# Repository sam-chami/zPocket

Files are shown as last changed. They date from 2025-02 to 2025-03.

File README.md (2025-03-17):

# zPocket
> WIP

certification-mark-ES000051-wide (https://certification.oshwa.org/es000051.html)

The zPocket is a modular, handheld portable Linux device with a square touchscreen as well as keyboard for input. The modularity allows you to use it as a Cyberdeck, Phone, or even satellite communicator.

## Significant features:
- Touchscreen 720x720 panel
- Blackberry Q10 Keyboard
- Raspberry Pi Compute Module 5
- Mini PCIe connector
- USB-C Dual-role Port and mini HDMI
- Magnetometer (Compass)
- Battery Charging and Gauge

## Assembly Render
Front                                                   |  Back
:------------------------------------------------------:|:--------------------------------------:
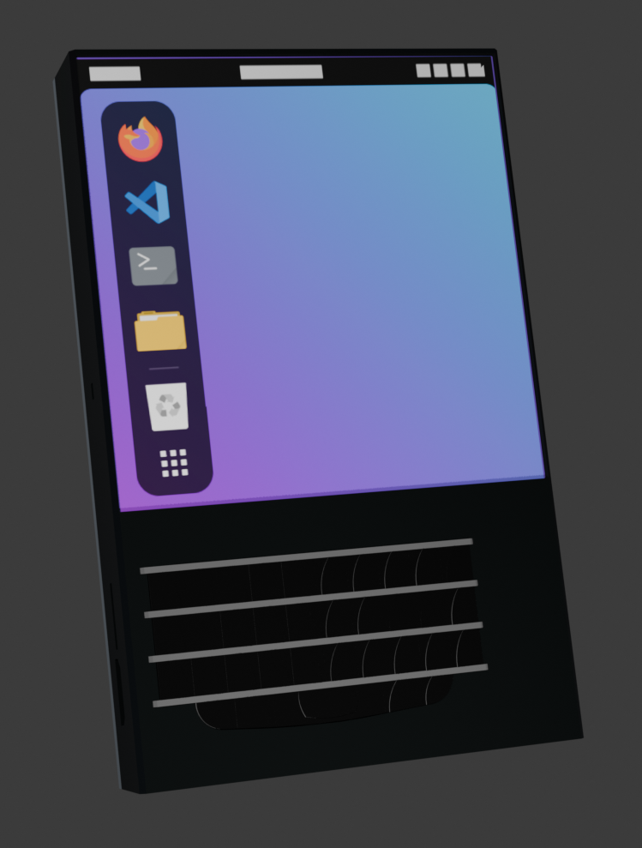
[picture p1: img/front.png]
Front of the zPocket inside the case
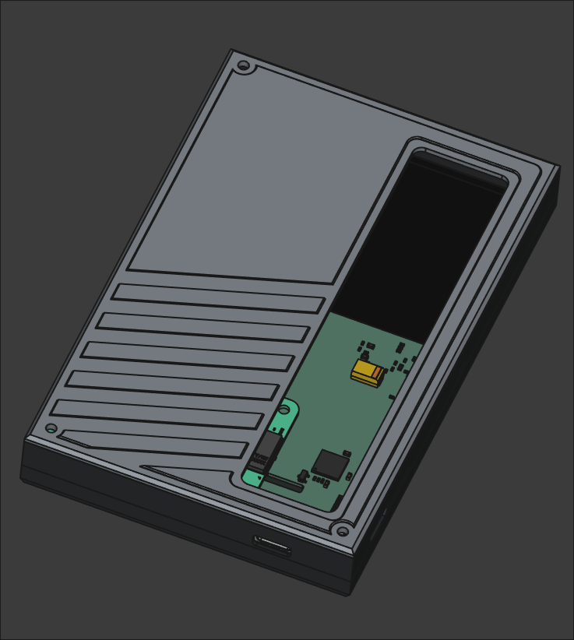
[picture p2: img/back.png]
Back of the zPocket.
  |  

## PCB
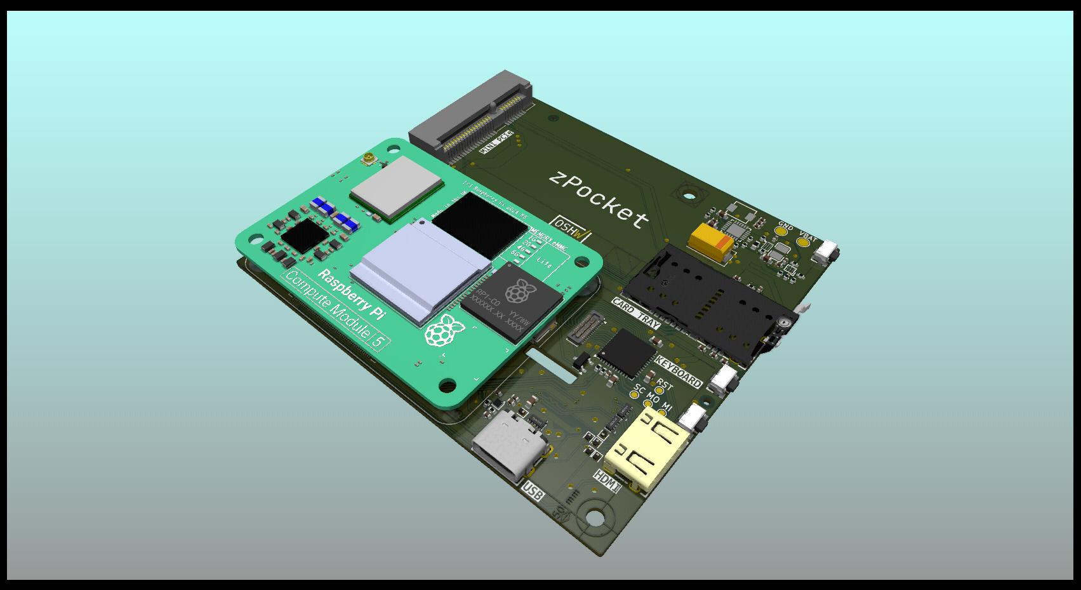
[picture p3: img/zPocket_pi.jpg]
Front of zPocket PCB


## Documentation
The documentation is available in [this repository's wiki page](https://github.com/sam-chami/zPocket/wiki)

## License
The zPocket hardware has a "CERN Open Hardware Licence Version 2 - Strongly Reciprocal".

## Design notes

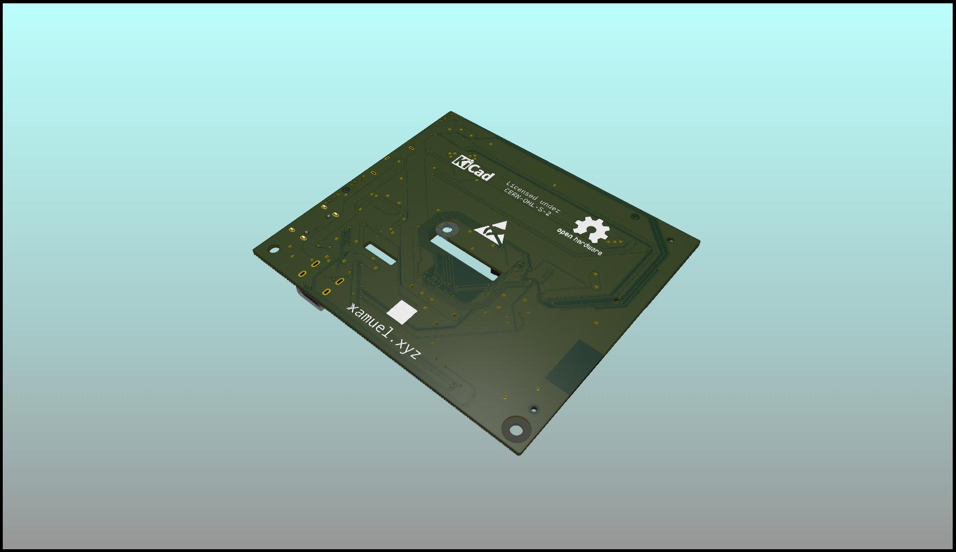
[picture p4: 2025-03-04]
img/zPocket_back.jpg

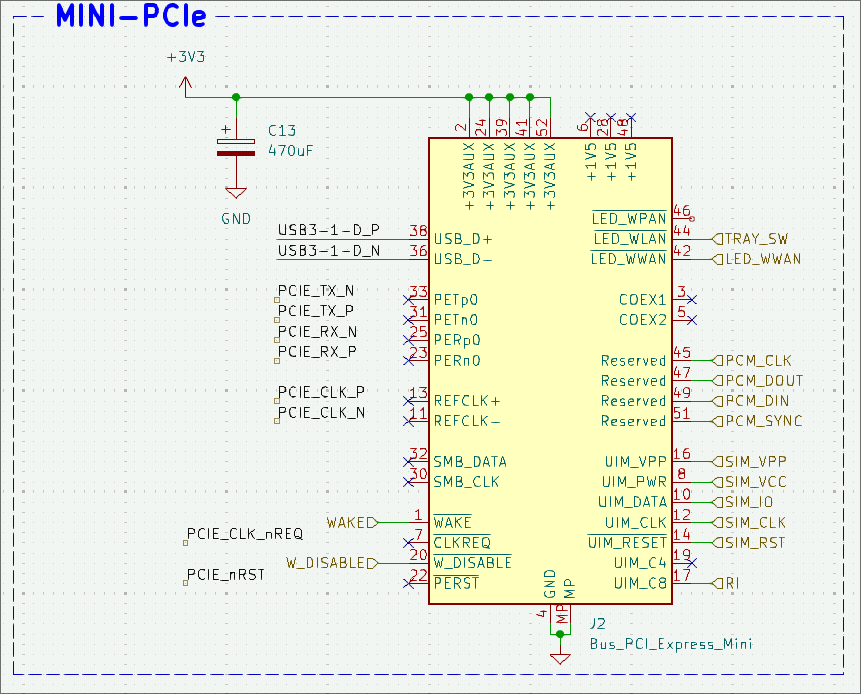
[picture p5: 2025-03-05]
img/mini_pcie.png

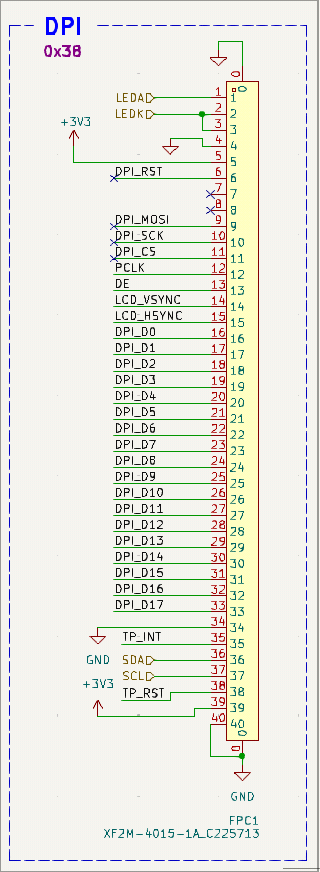
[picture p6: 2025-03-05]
img/DPI.png

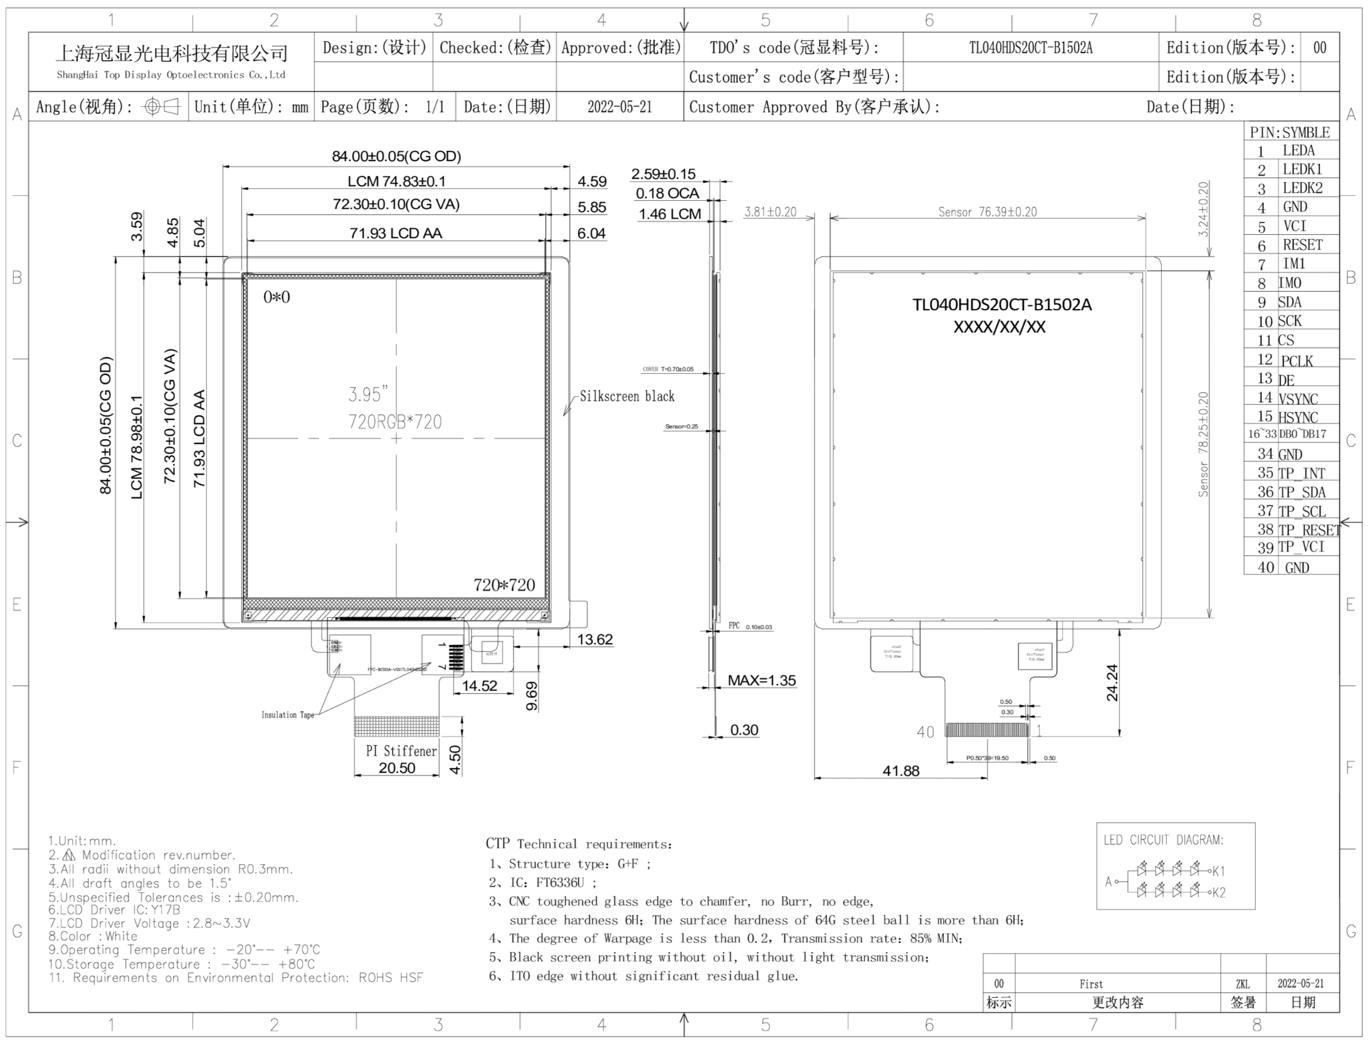
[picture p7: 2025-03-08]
img/display_draw.png

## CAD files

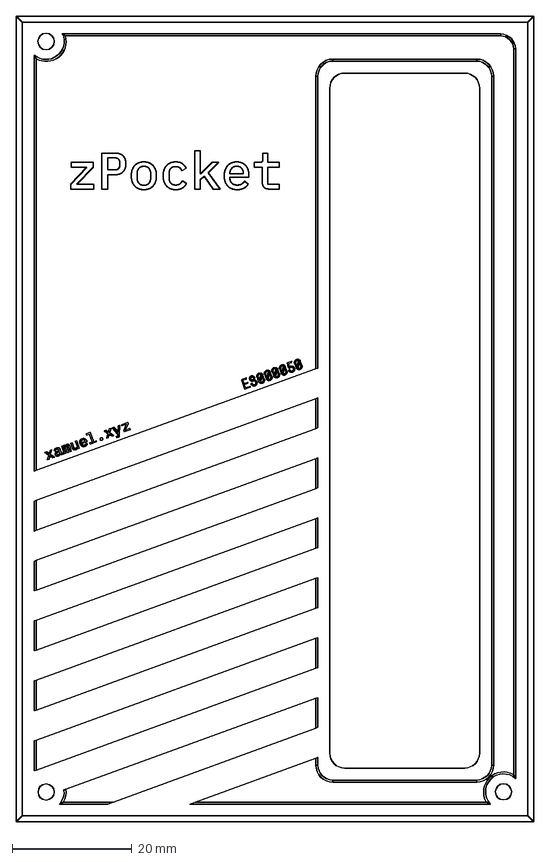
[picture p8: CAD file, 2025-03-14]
Case/drawing.dxf
86.3 x 134.5 mm

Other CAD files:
Case/zPocket-Back.step
Case/zPocket-Back.dfx.step
Case/pcb.step

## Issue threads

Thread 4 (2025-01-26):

Battery

sam-chami, 2025-01-26:
Everything is done, but in

### **THE CHARGER**

- TODO: Set resistor divider according to temp range.

### **THE GAUGE**

- TODO: Setup BIN pin according to removable or fixed battery.

### **BUCK BOOST**

- Set enable pin in order to turn it off with the CM4/5

sam-chami, 2025-03-04:
Finished, right now we're using a normal soldered battery, if possible we will use a removable one.

Closed 2025-03-04.

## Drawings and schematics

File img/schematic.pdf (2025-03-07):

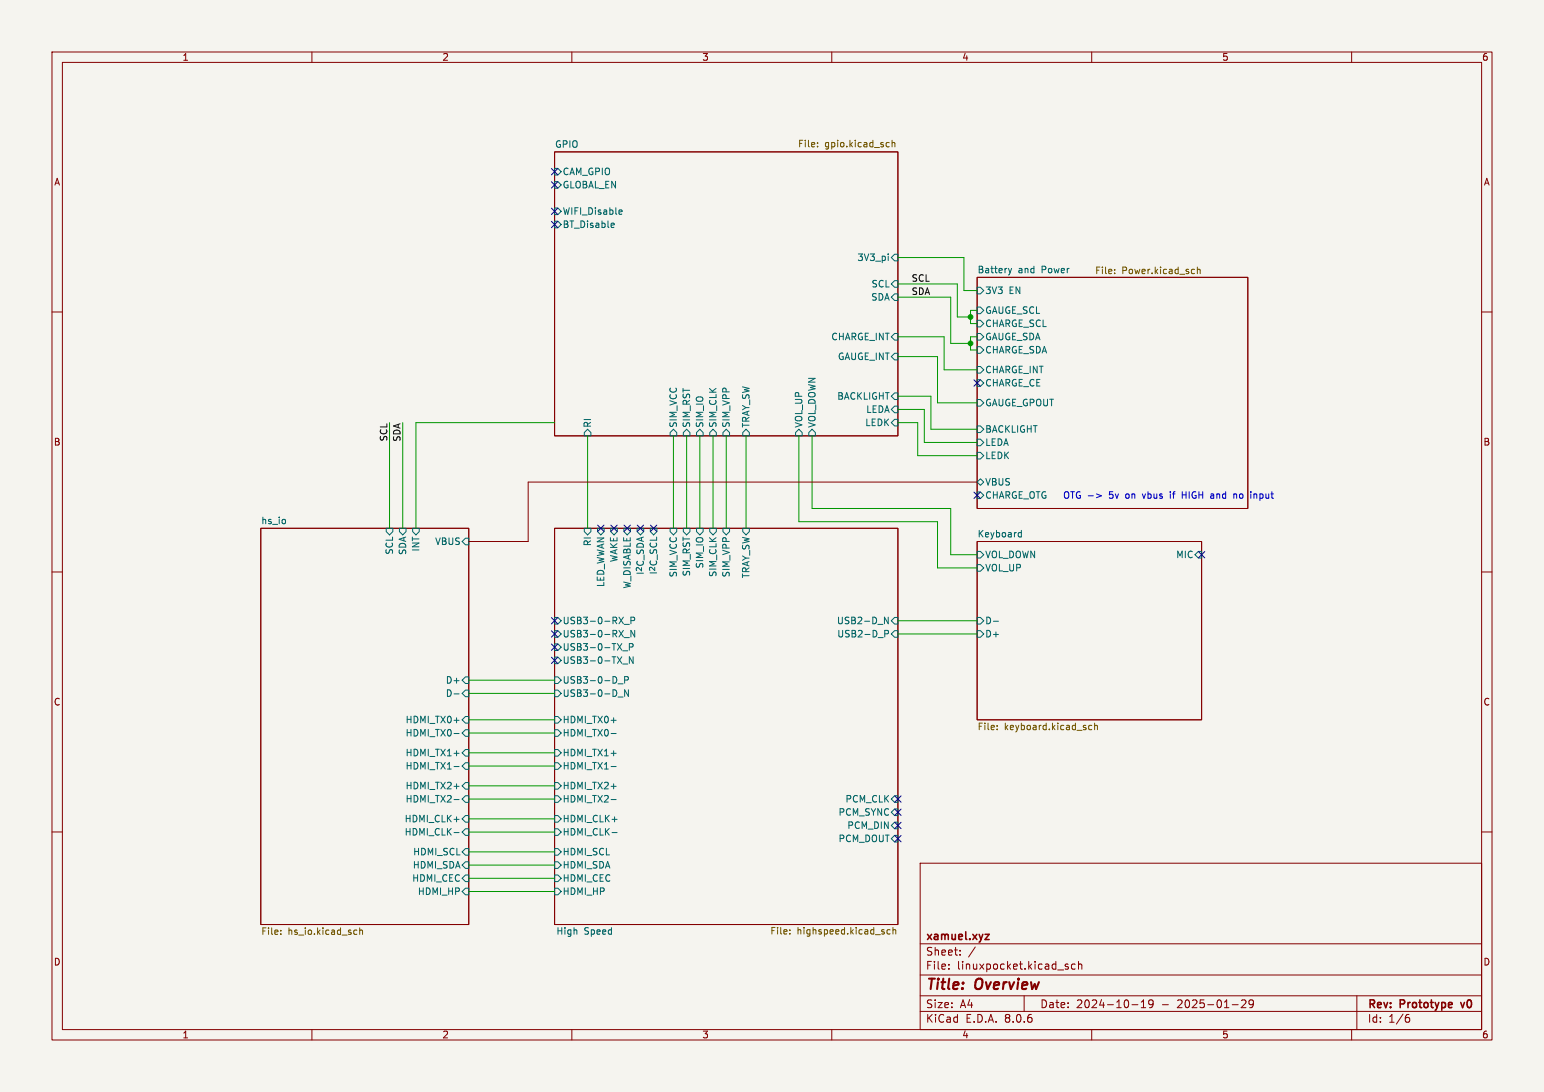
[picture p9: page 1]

Keyboard File: keyboard.kicad_sch SDA
hs_io File: hs_io.kicad_sch

File: linuxpocket.kicad_sch Sheet: / xamuel.xyz HDMI_TX1+ HDMI_TX1- HDMI_TX0+ HDMI_TX2+ HDMI_TX2- HDMI_TX0- HDMI_CLK- HDMI_CLK+ HDMI_SCL HDMI_SDA HDMI_CEC

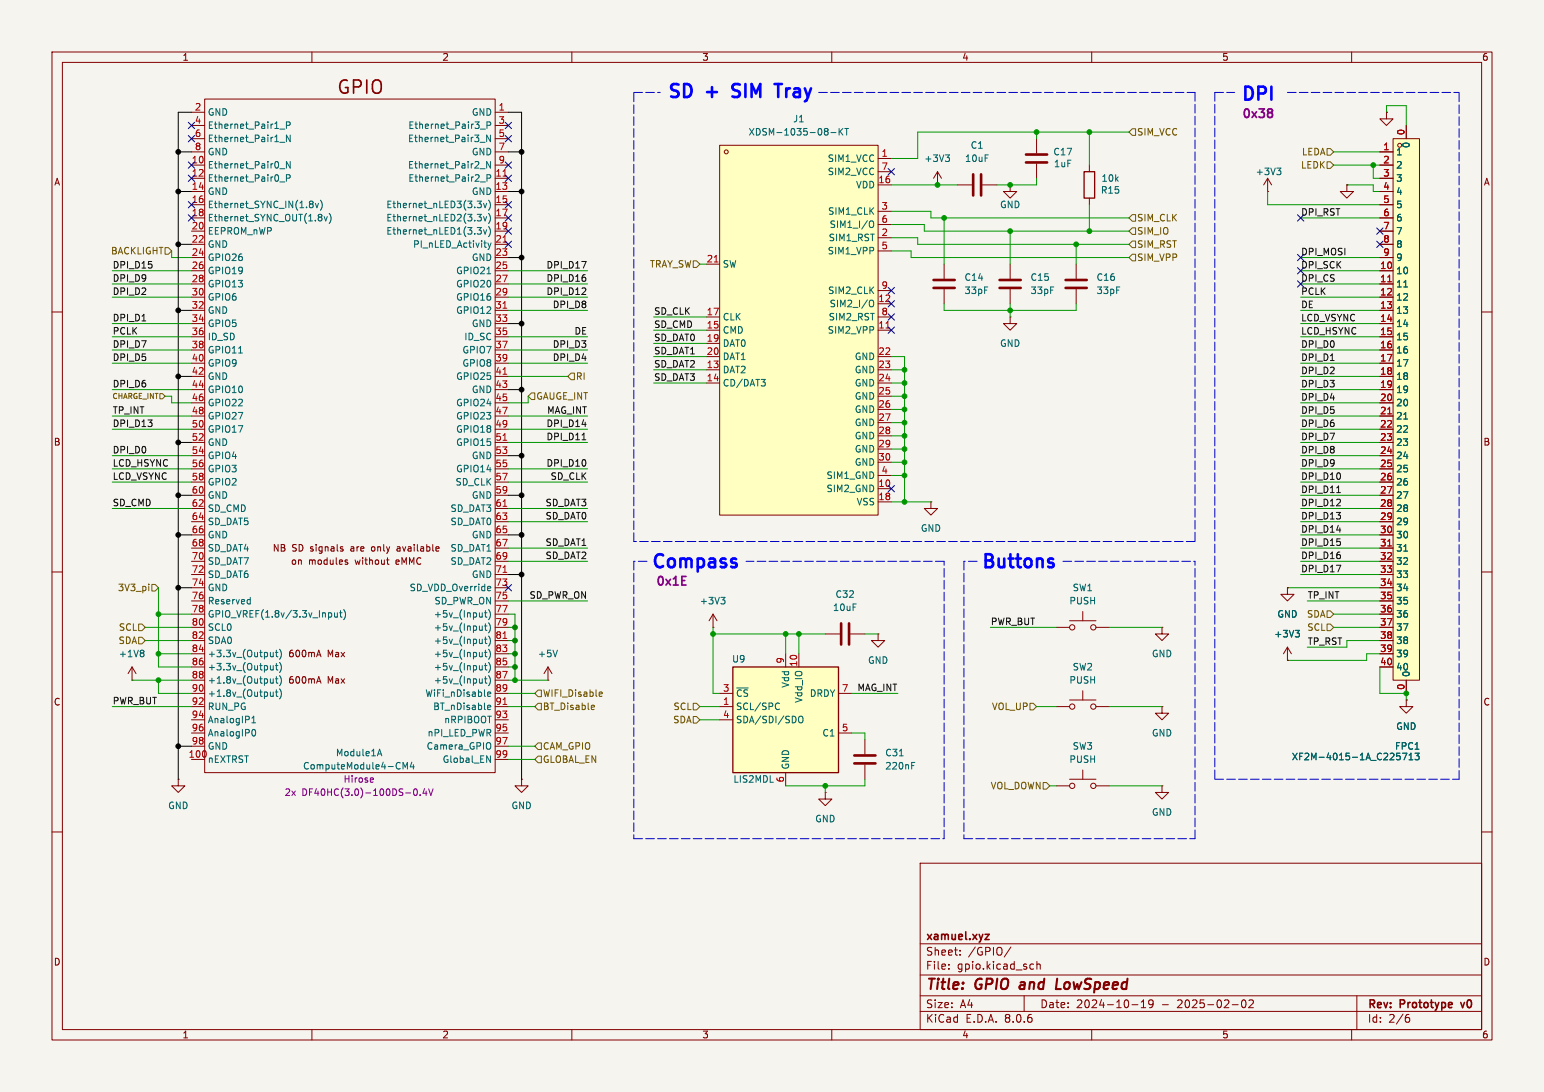
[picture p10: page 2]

600mA Max 600mA Max NB SD signals are only available

File: gpio.kicad_sch Sheet: /GPIO/ xamuel.xyz C32

Id: 2/6 Title: GPIO and LowSpeed

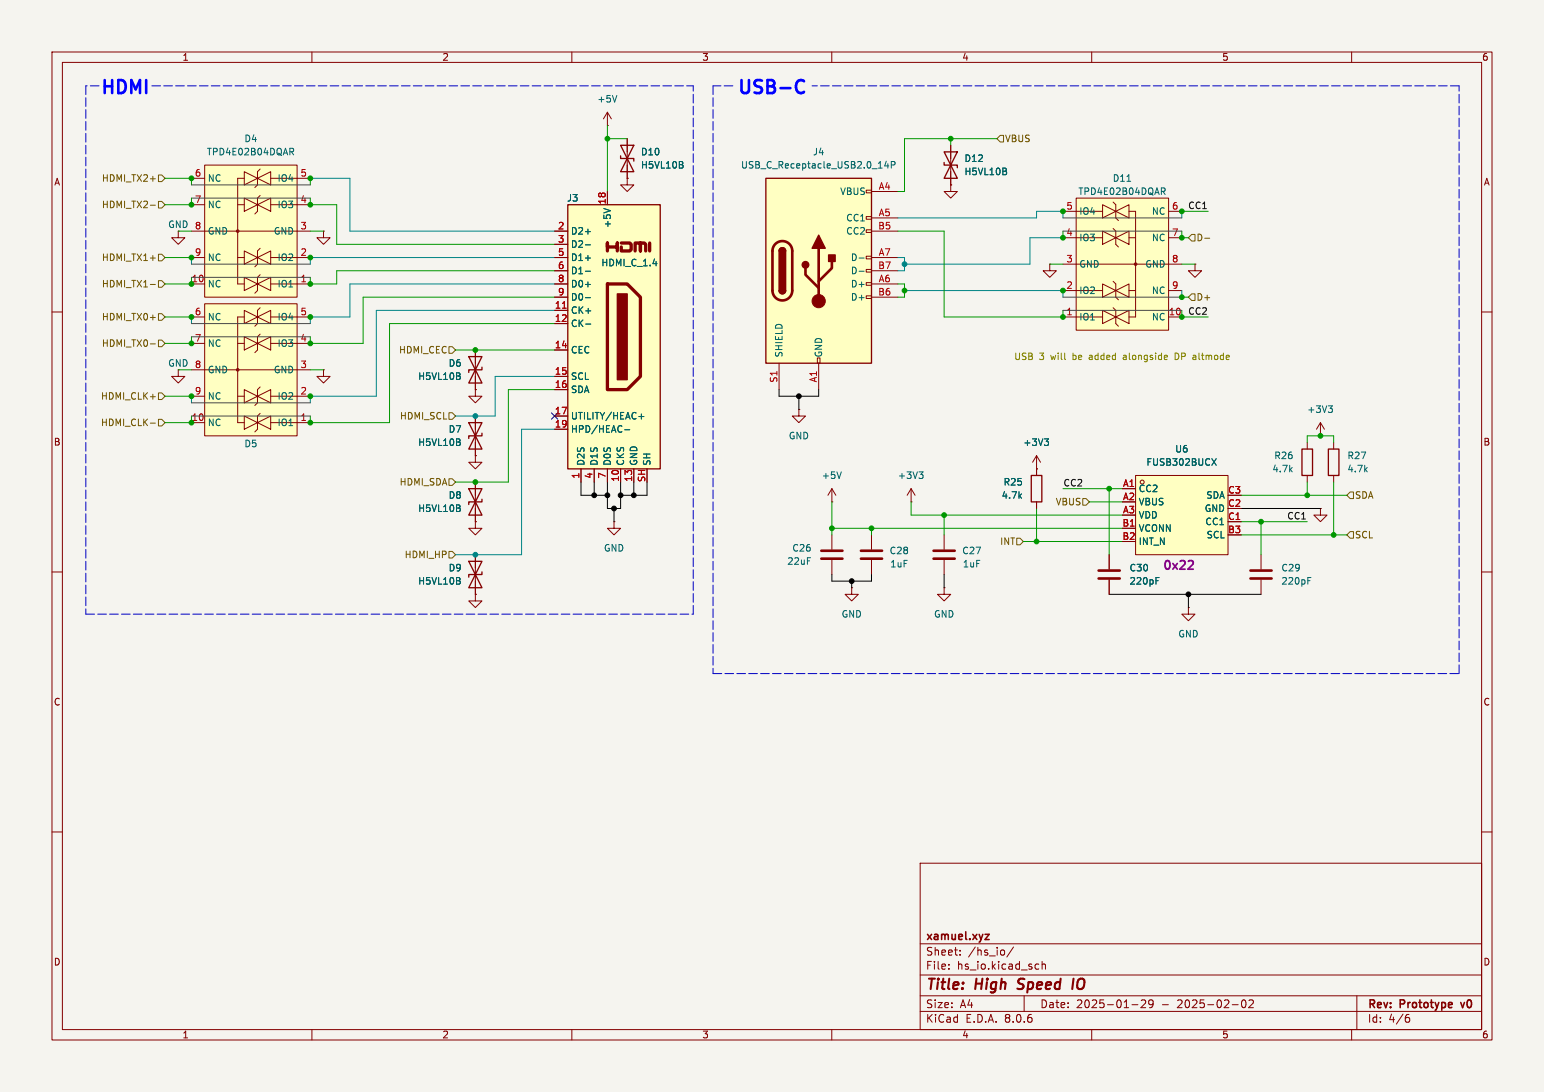
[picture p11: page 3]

1 CKS 10 CK+ 11 CK- 12 GND 13 CEC 14 SCL 15 SDA 16 UTILITY/HEAC+ 17 +5V 18 HPD/HEAC- 19 D2+ 2 D2- 3 D1S

xamuel.xyz
File: hs_io.kicad_sch Sheet: /hs_io/
Id: 4/6 Title: High Speed IO

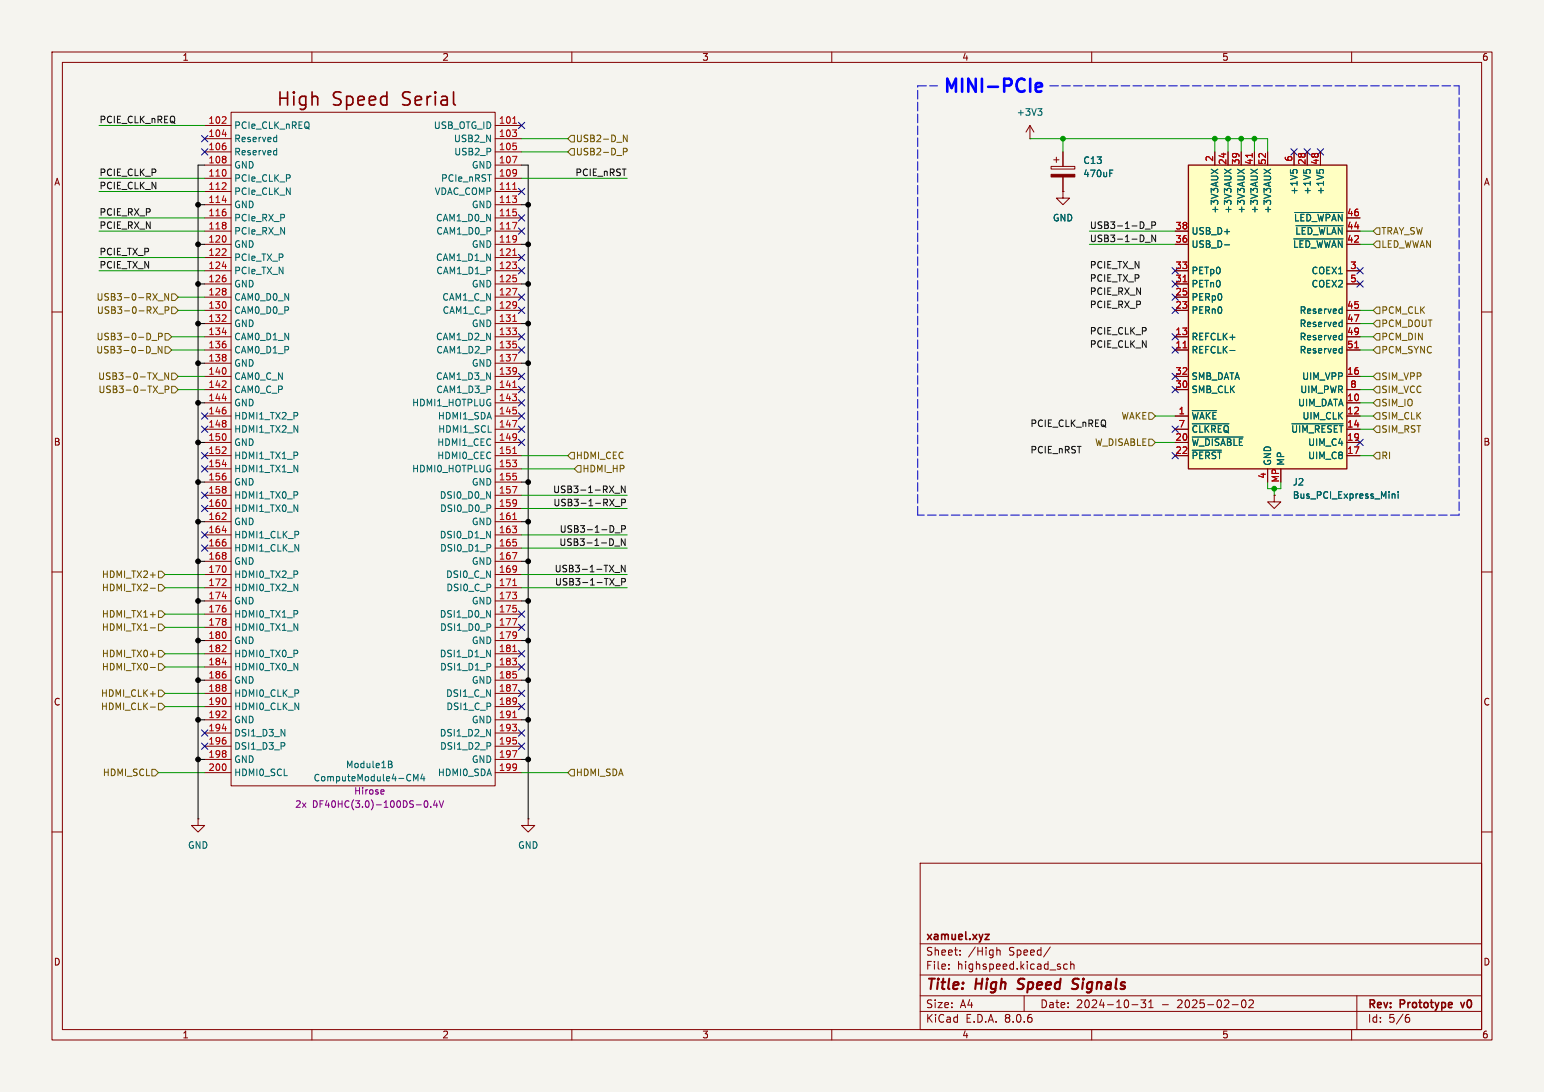
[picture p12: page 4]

xamuel.xyz
Id: 5/6 Title: High Speed Signals

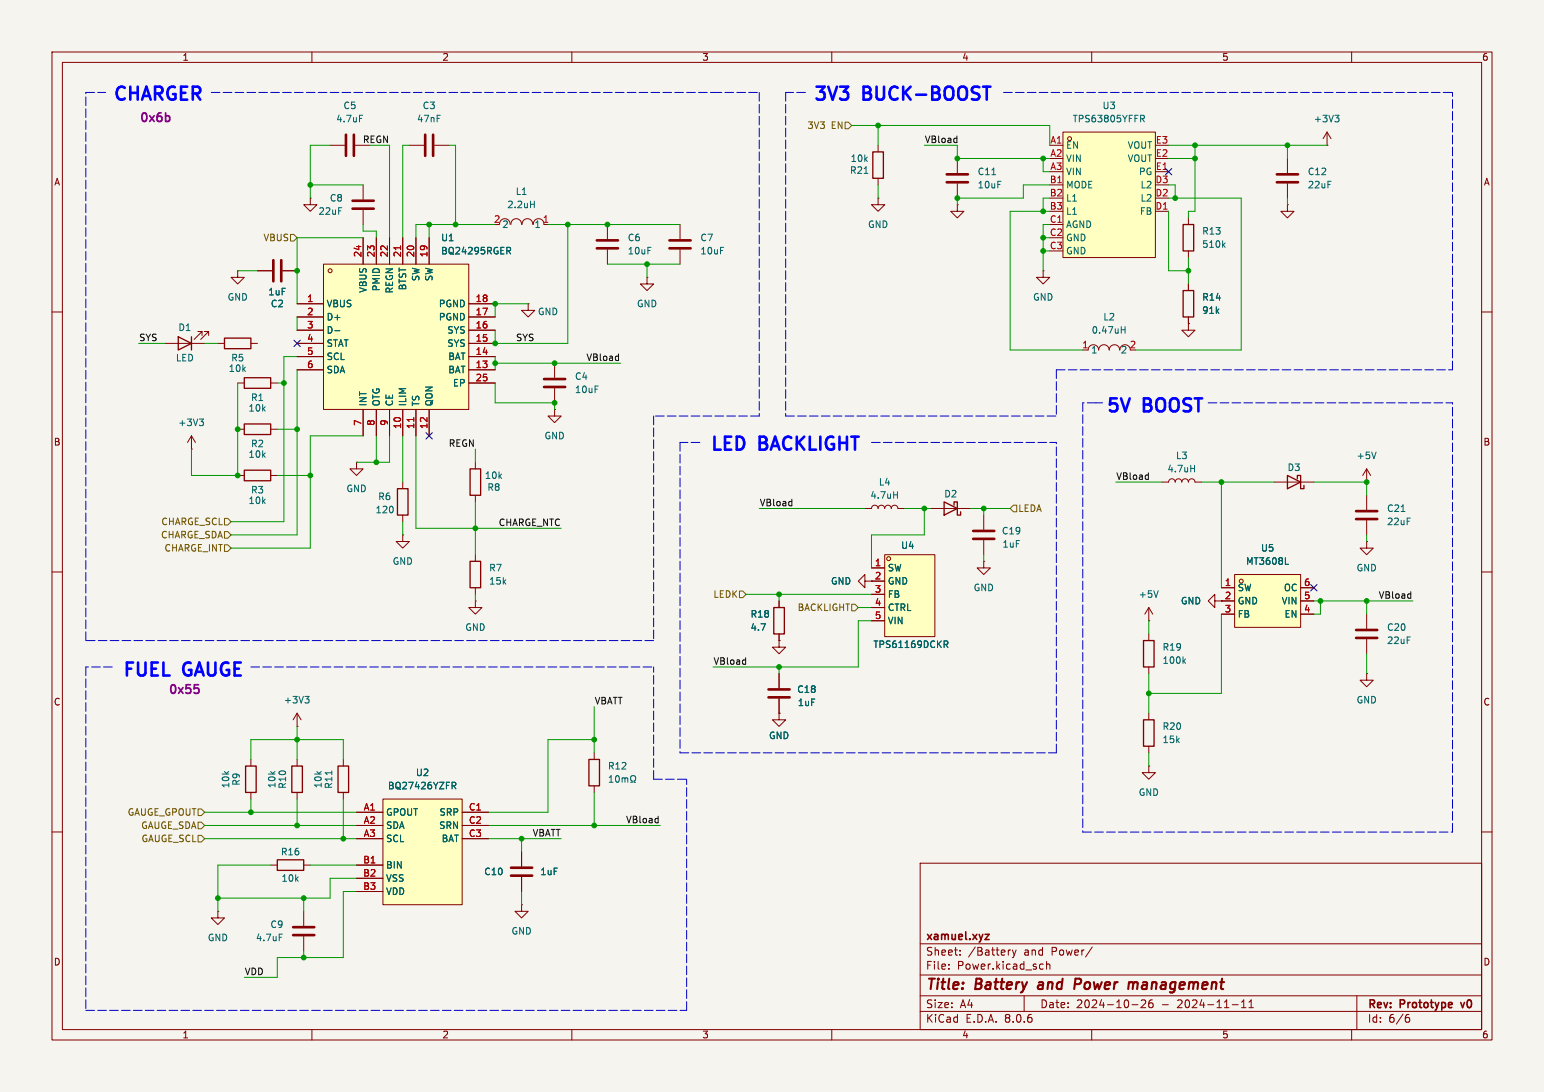
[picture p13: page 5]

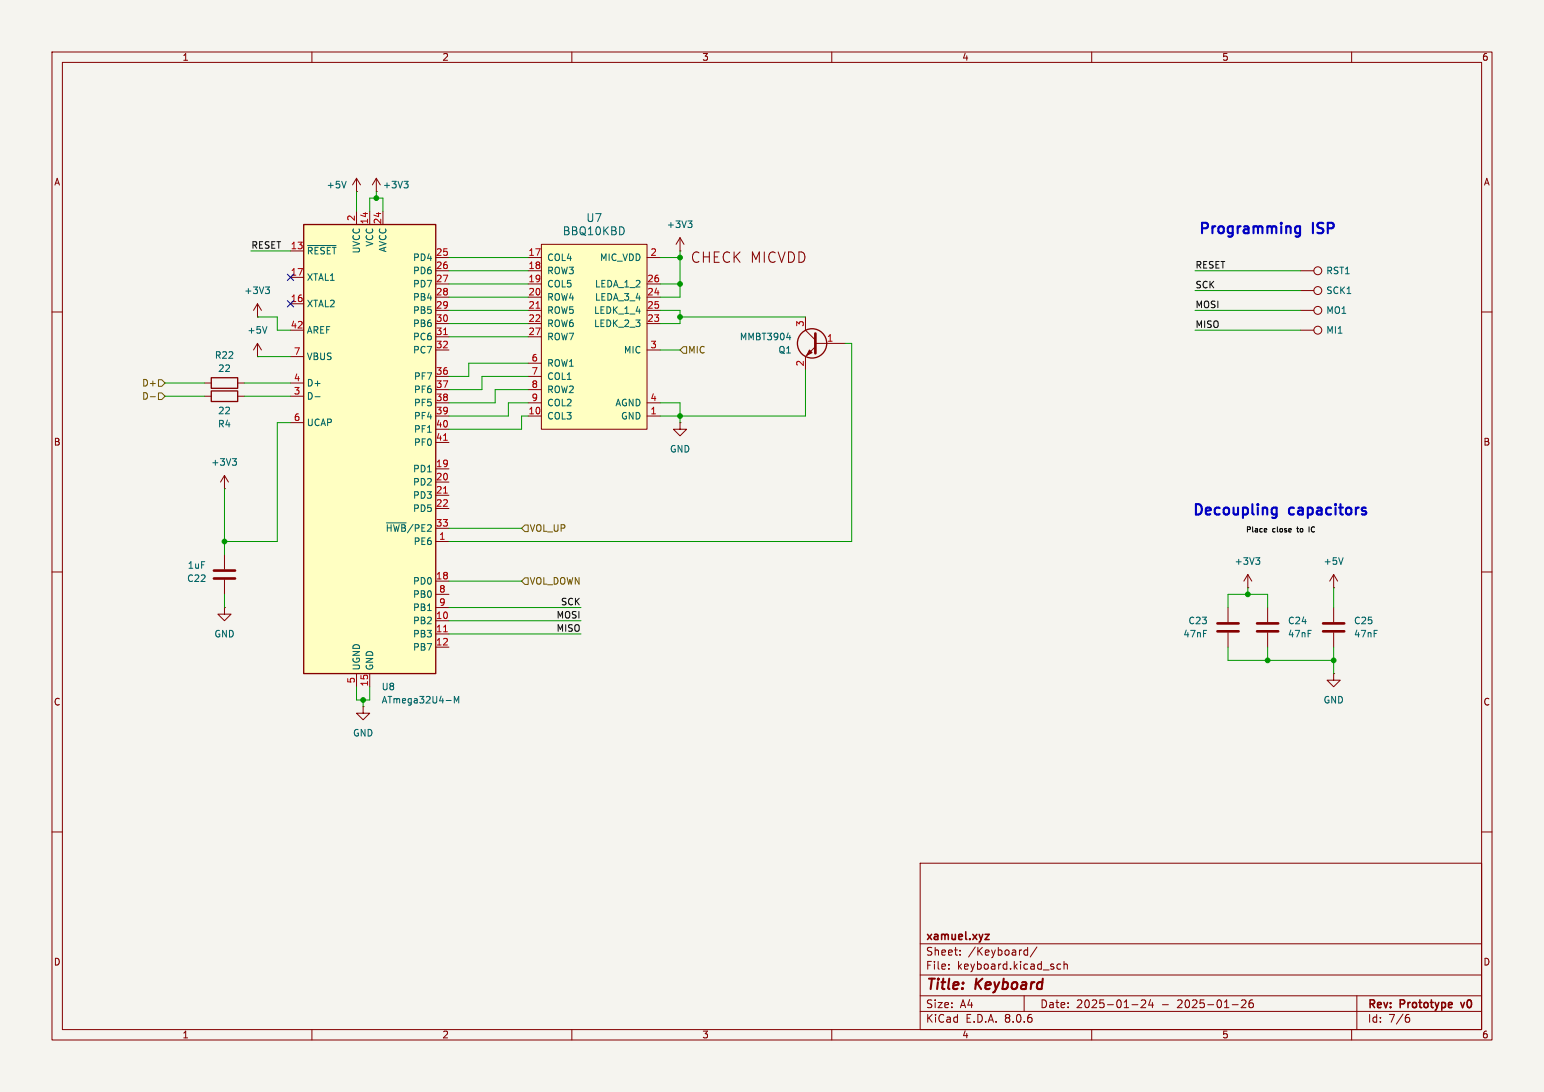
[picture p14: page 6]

2 PD2 20 PD3 21 PD5 22 AVCC 24 PD4 25 PD6 26 PD7 27 PB4 28 PB5 29 D- 3 PB6 30 PC6 31 PC7 32 ~{HWB}/PE233 PF7 36 PF6 37 PF5 38 PF4 39 D+ 4 PF1 40 PF0 41 AREF 42 UGND

Place close to IC Decoupling capacitors

xamuel.xyz
File: keyboard.kicad_sch Sheet: /Keyboard/
Id: 7/6 Title: Keyboard

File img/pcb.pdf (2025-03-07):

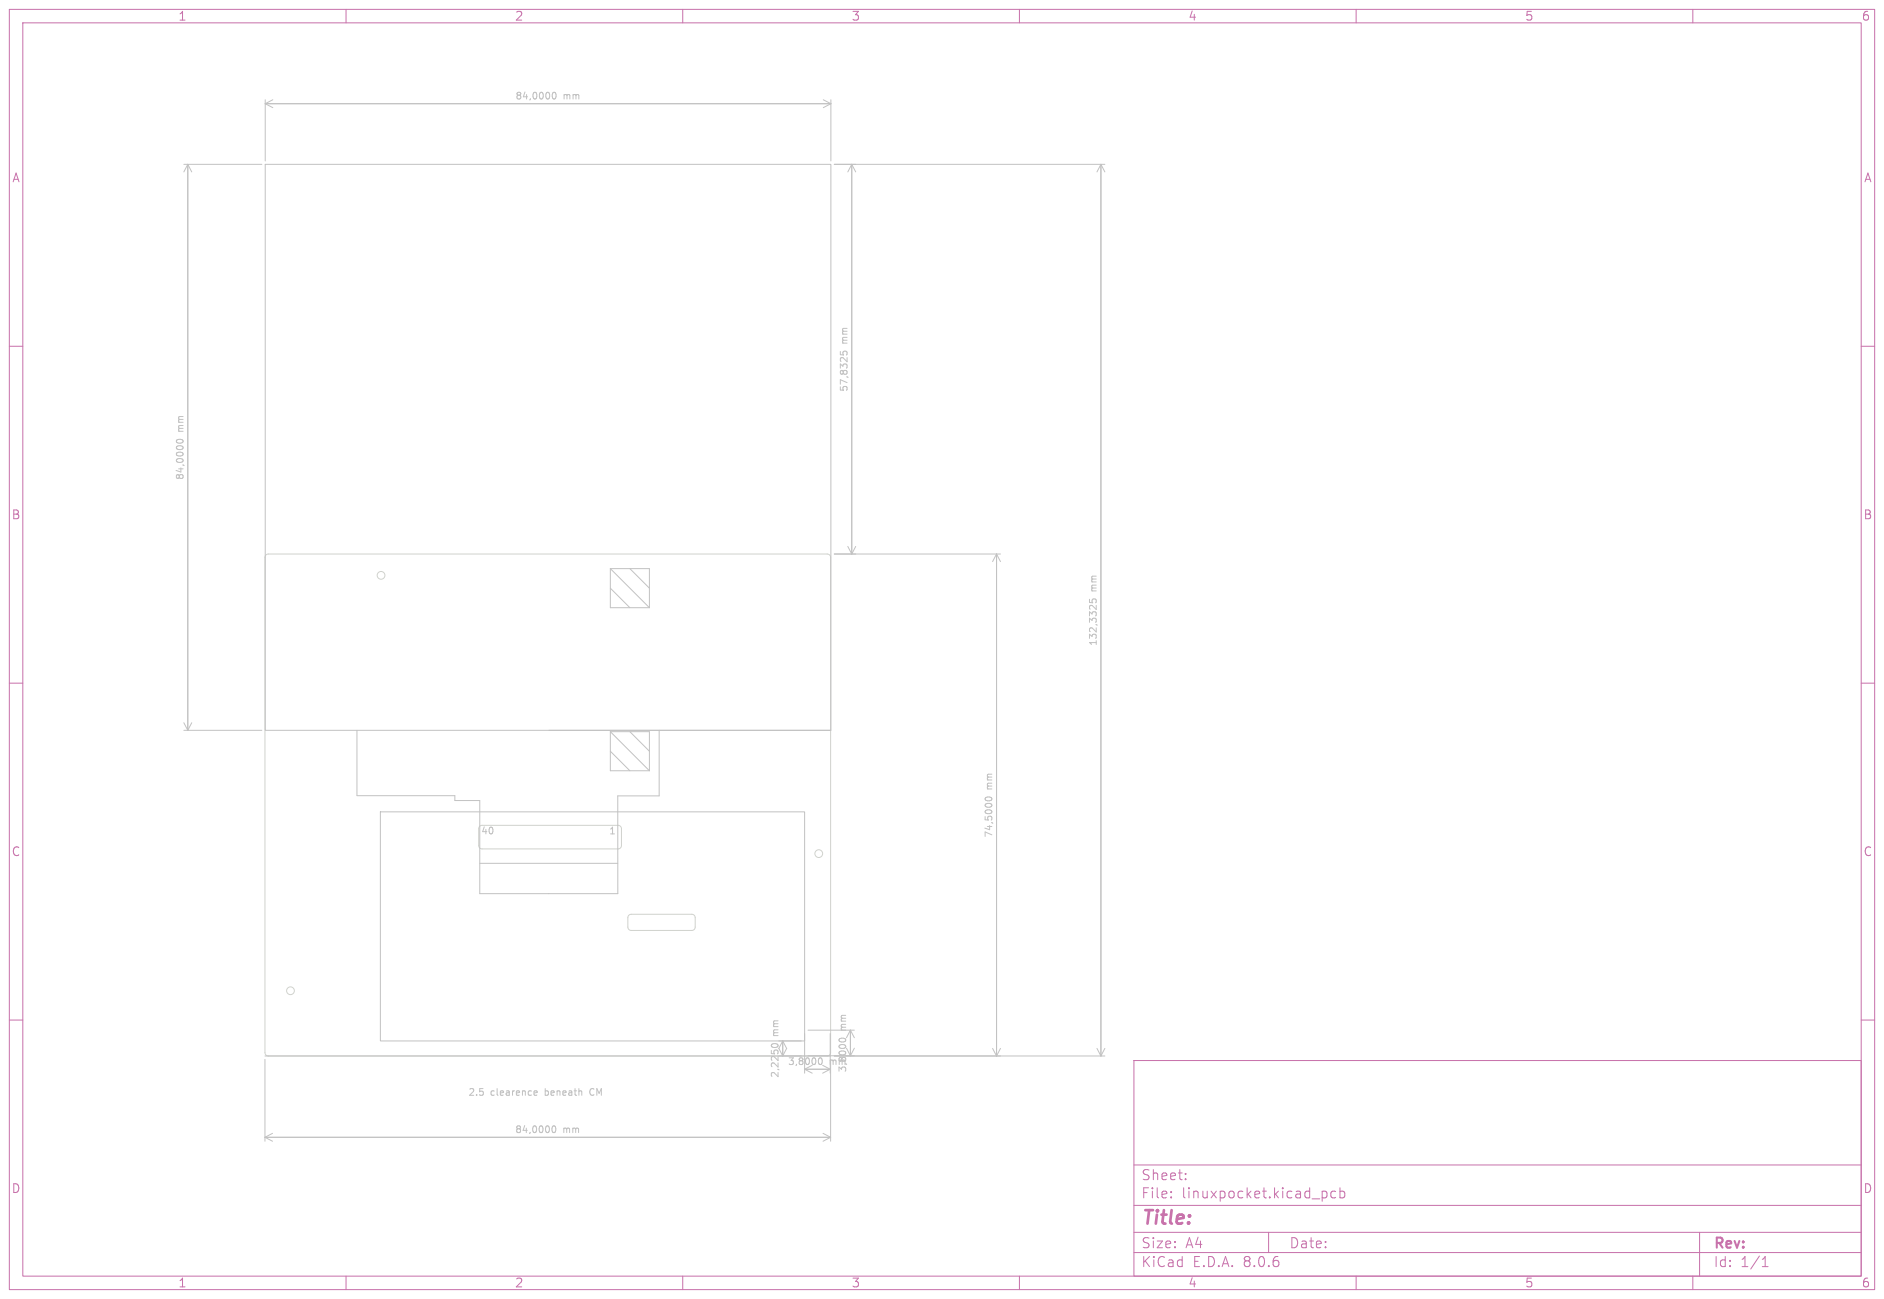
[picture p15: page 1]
6 ABCD; ABCD Date: KiCad; E.D.A. 8.0.6 Size: A4; Rev:; 2.5 clearence; beneath CM

Id: 1/1 Title: File: linuxpocket.kicad_pcb Sheet: ²,2250 mm

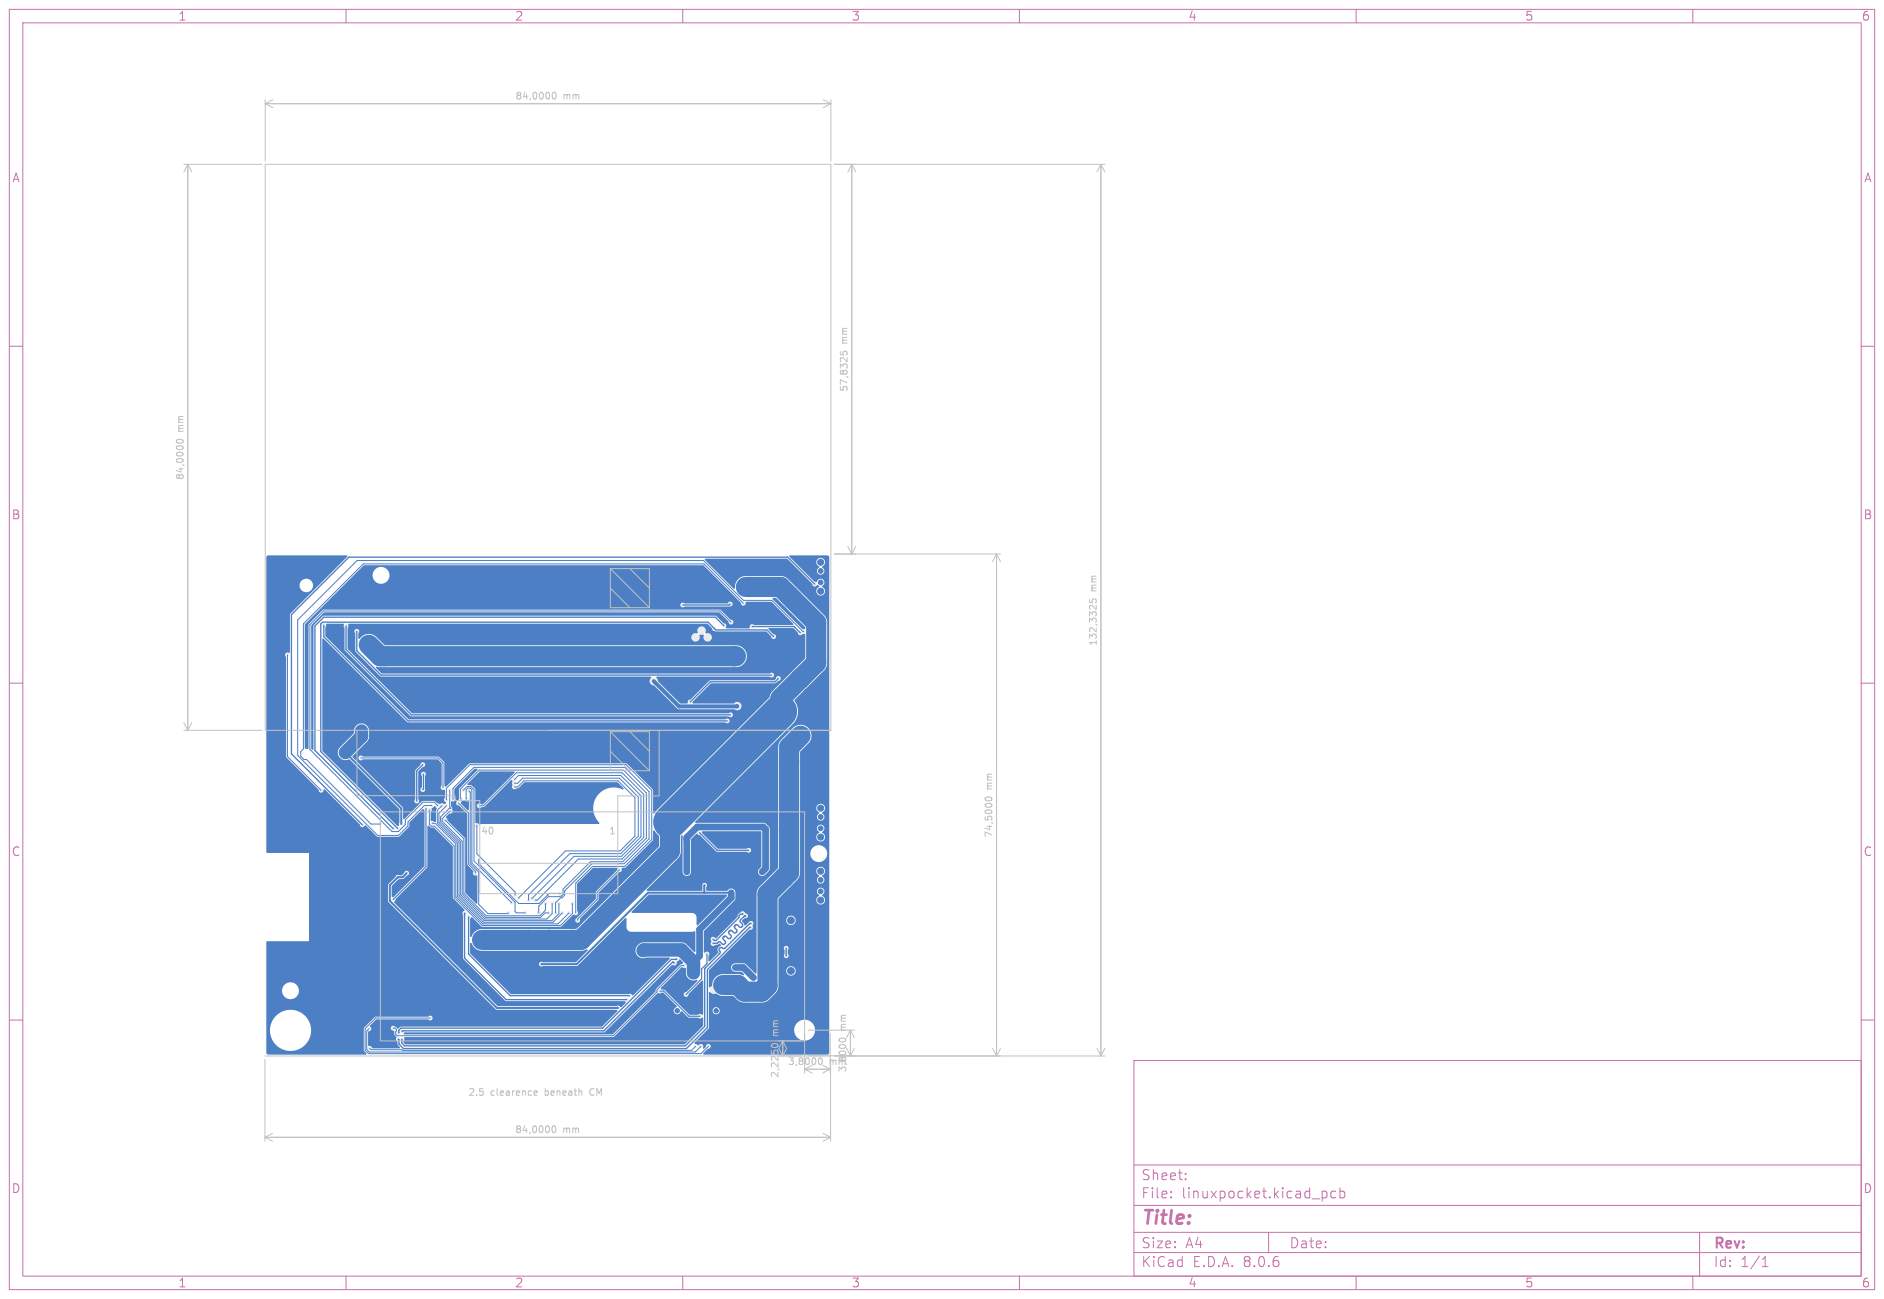
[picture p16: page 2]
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

Id: 1/1 Title: File: linuxpocket.kicad_pcb Sheet: ²,2250 mm

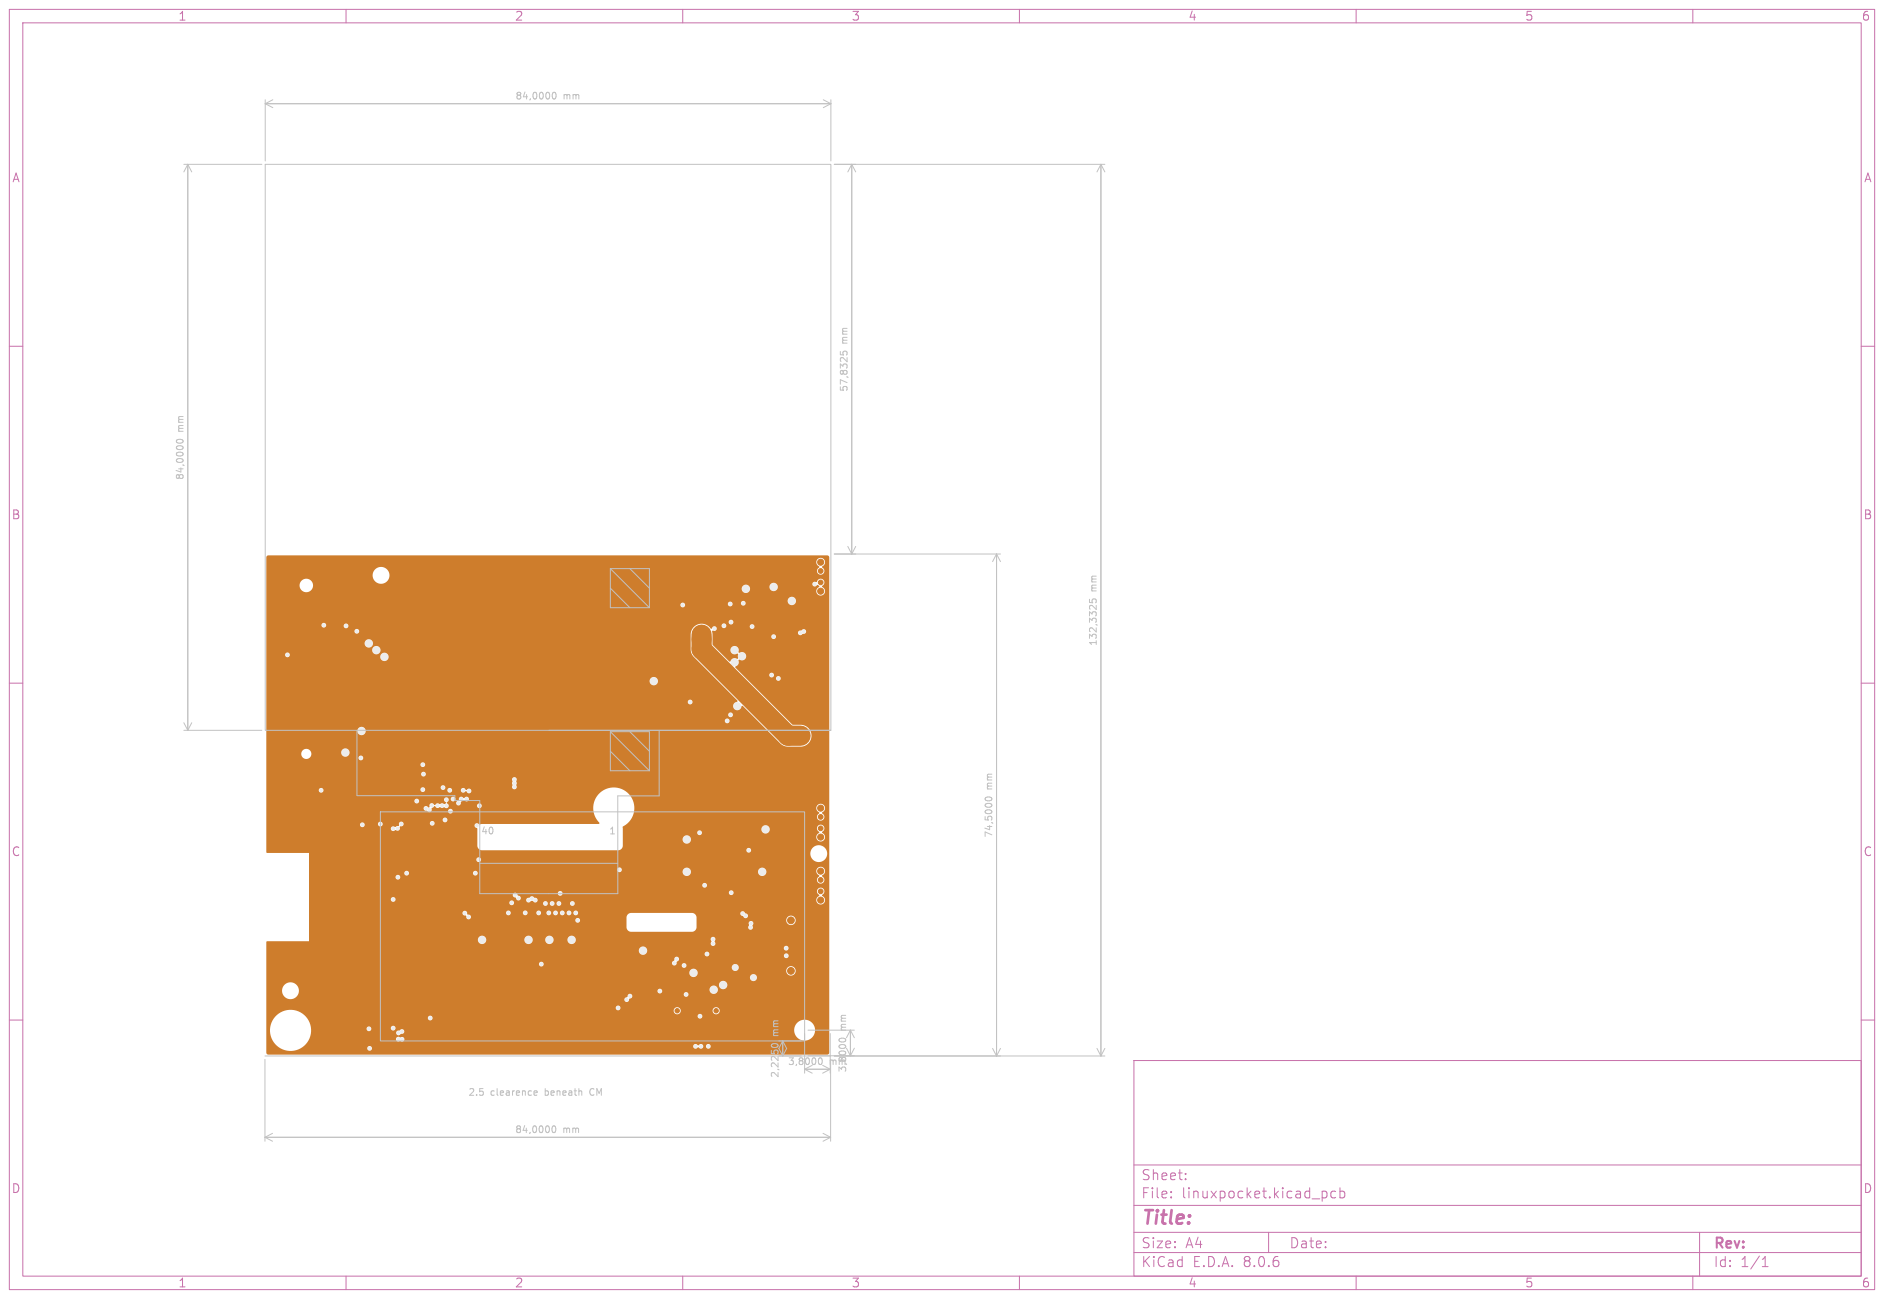
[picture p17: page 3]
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

Id: 1/1 Title: File: linuxpocket.kicad_pcb Sheet: ²,2250 mm

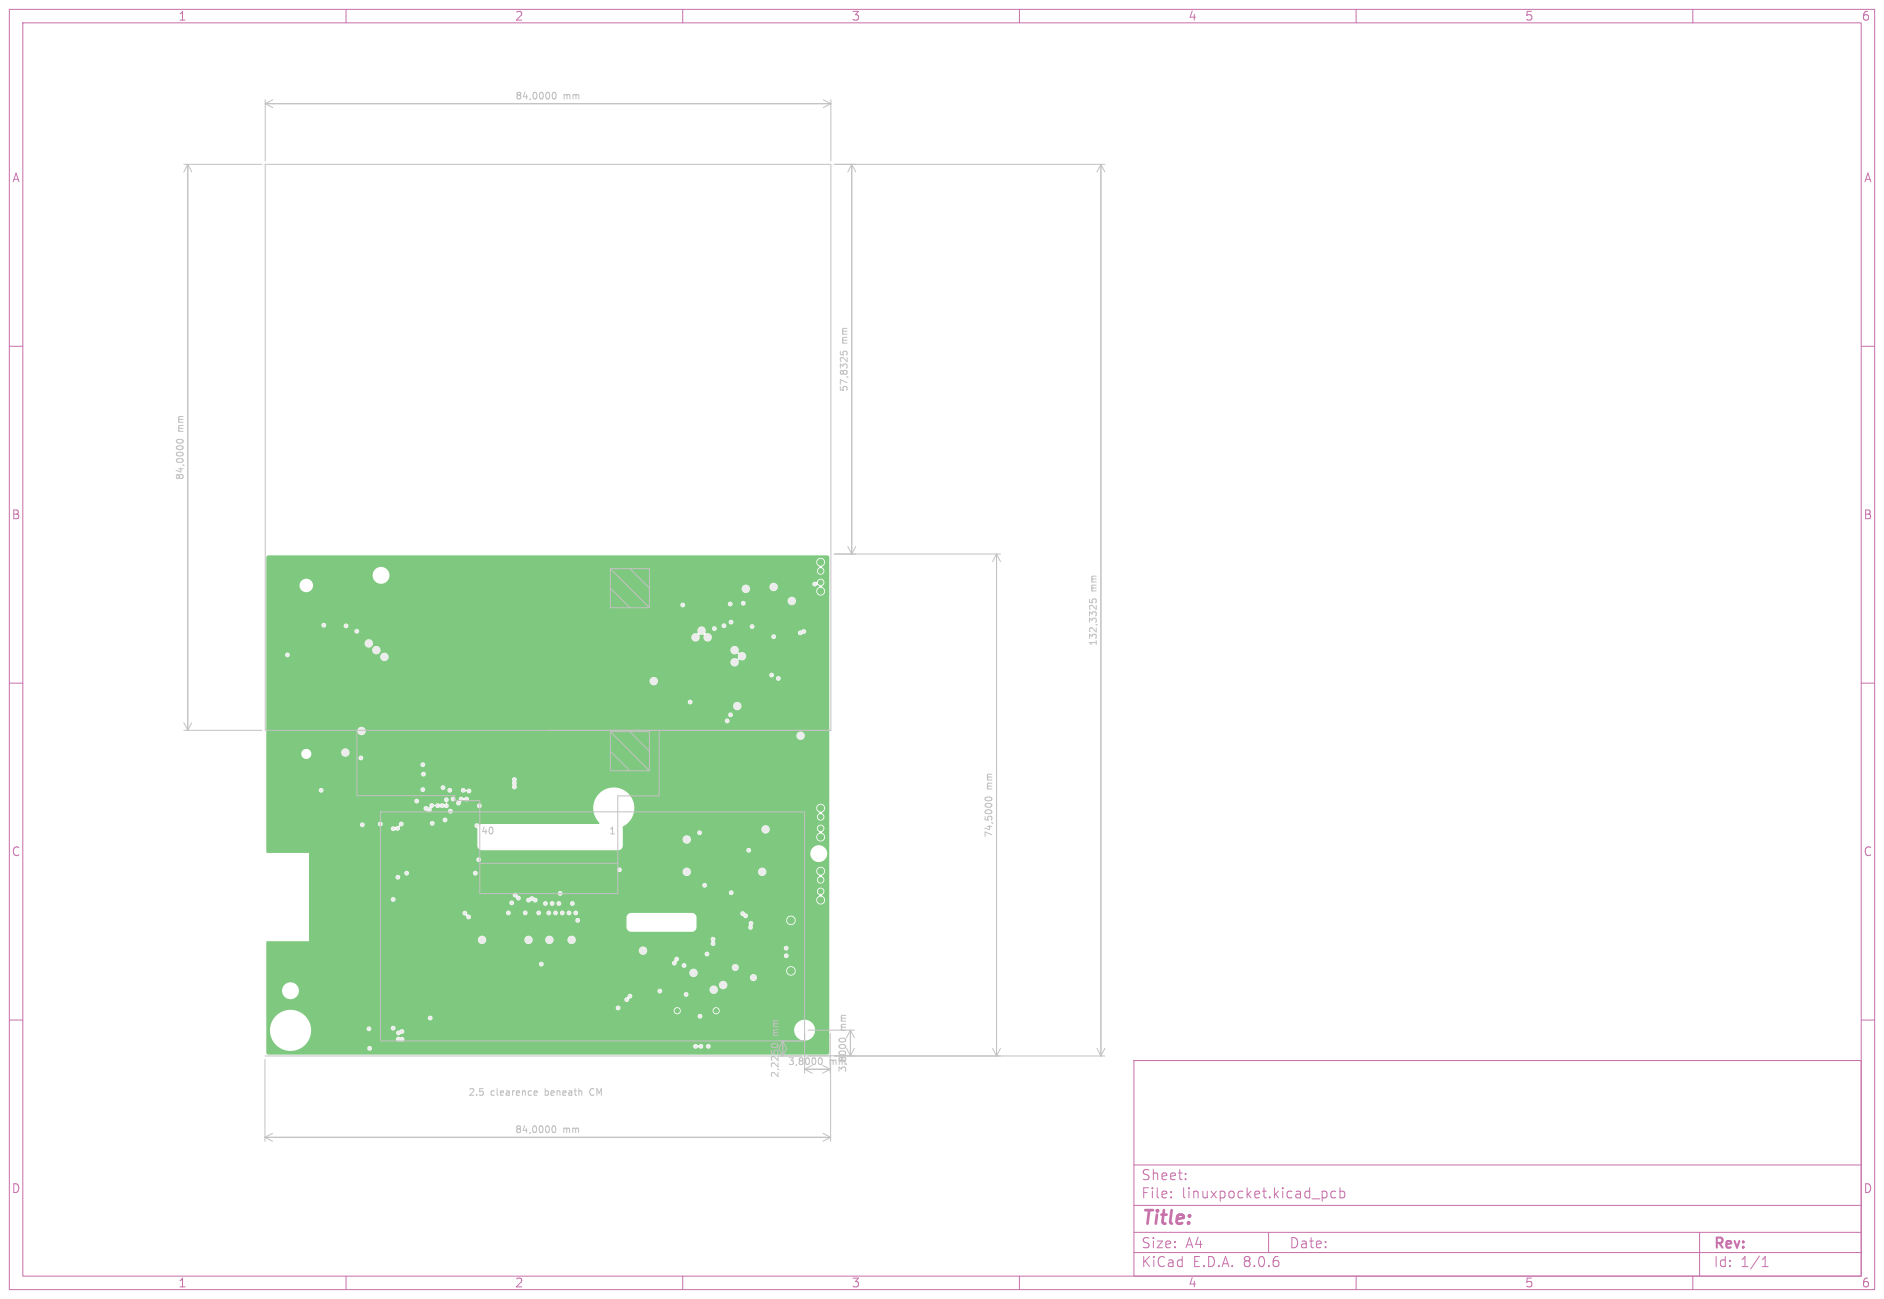
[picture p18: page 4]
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

Id: 1/1 Title: File: linuxpocket.kicad_pcb Sheet: ²,2250 mm

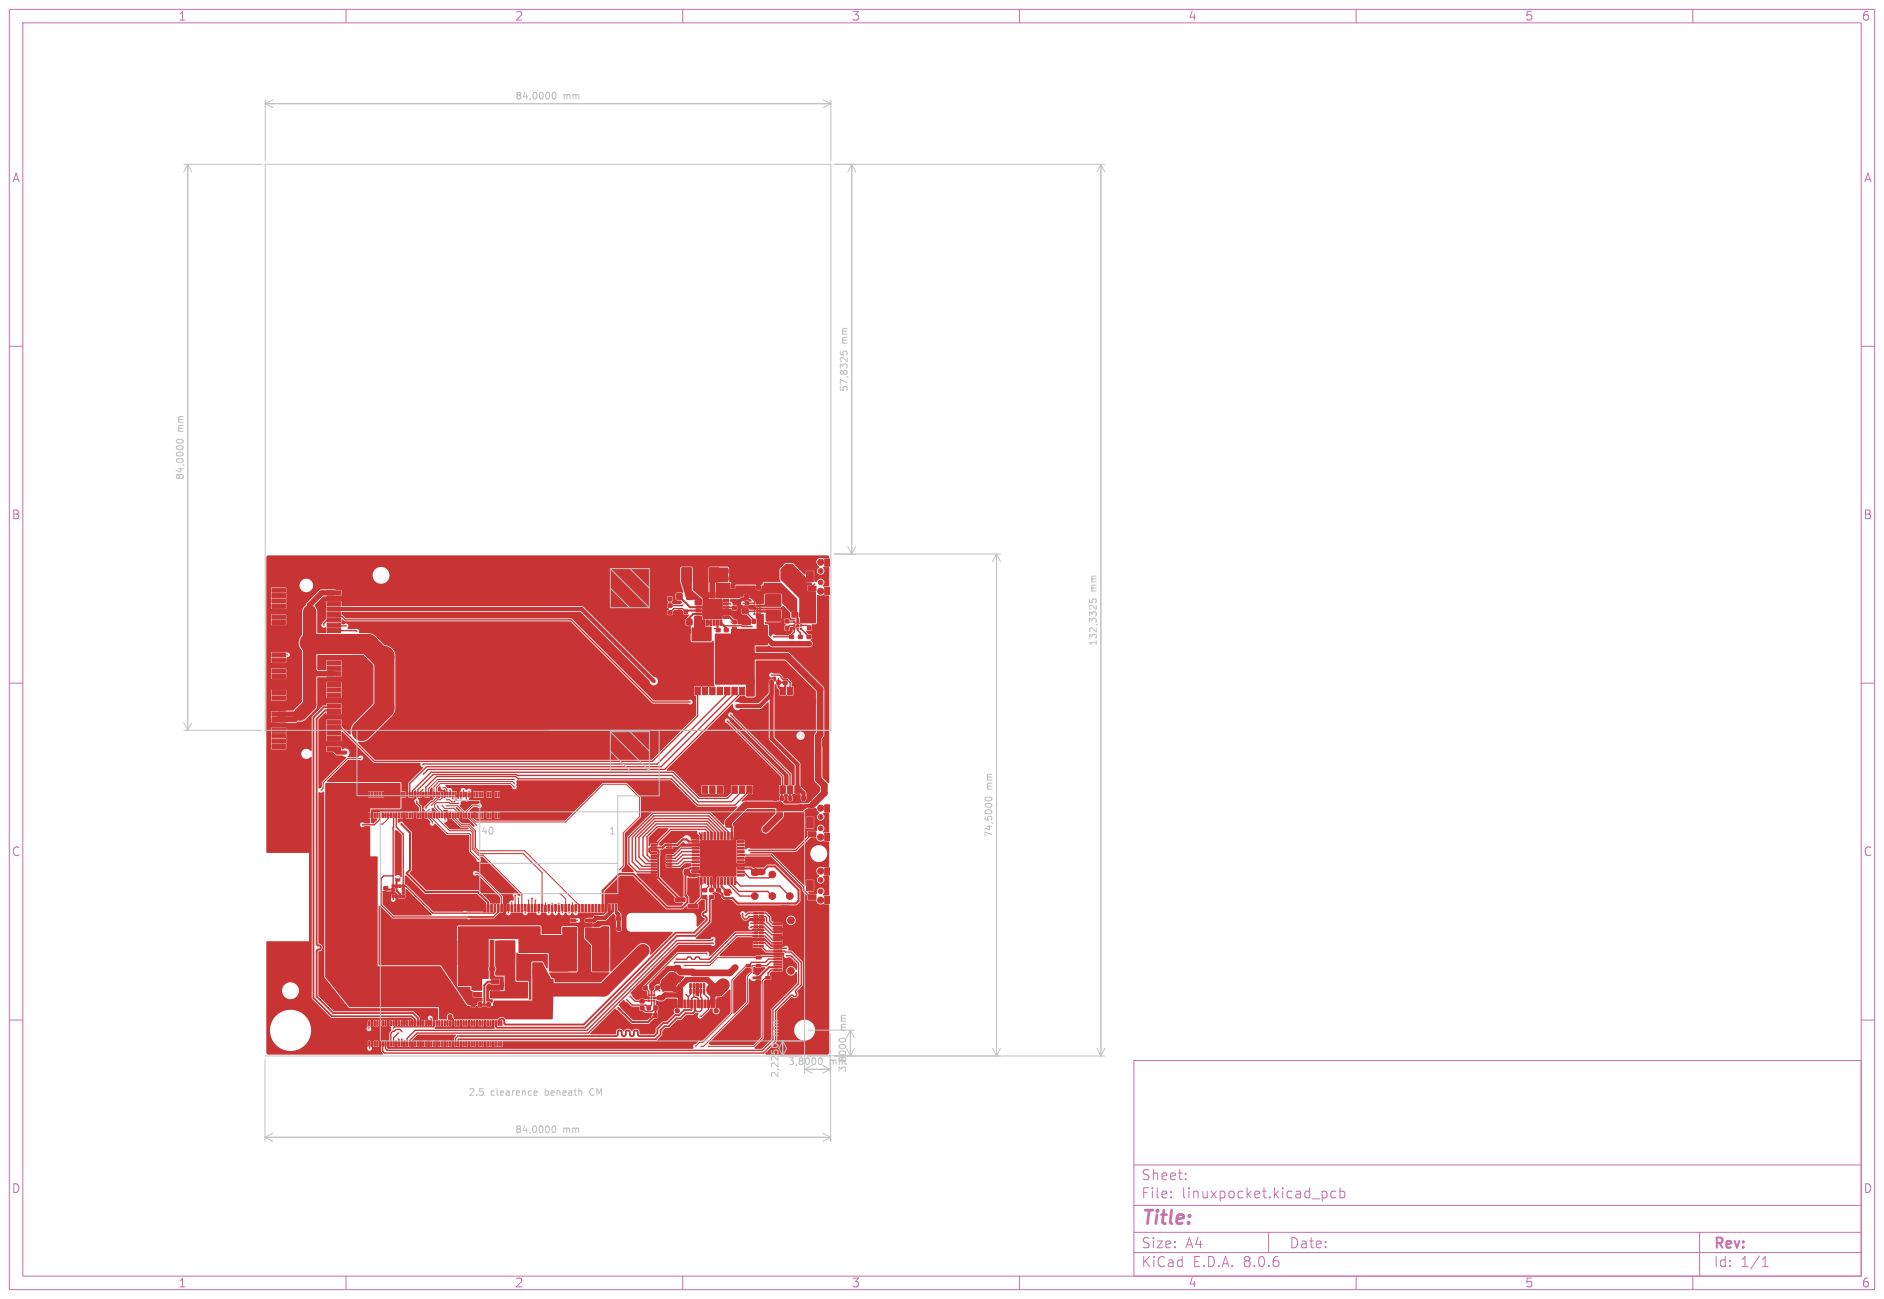
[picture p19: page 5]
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

Id: 1/1 Title: File: linuxpocket.kicad_pcb Sheet: ²,2250 mm

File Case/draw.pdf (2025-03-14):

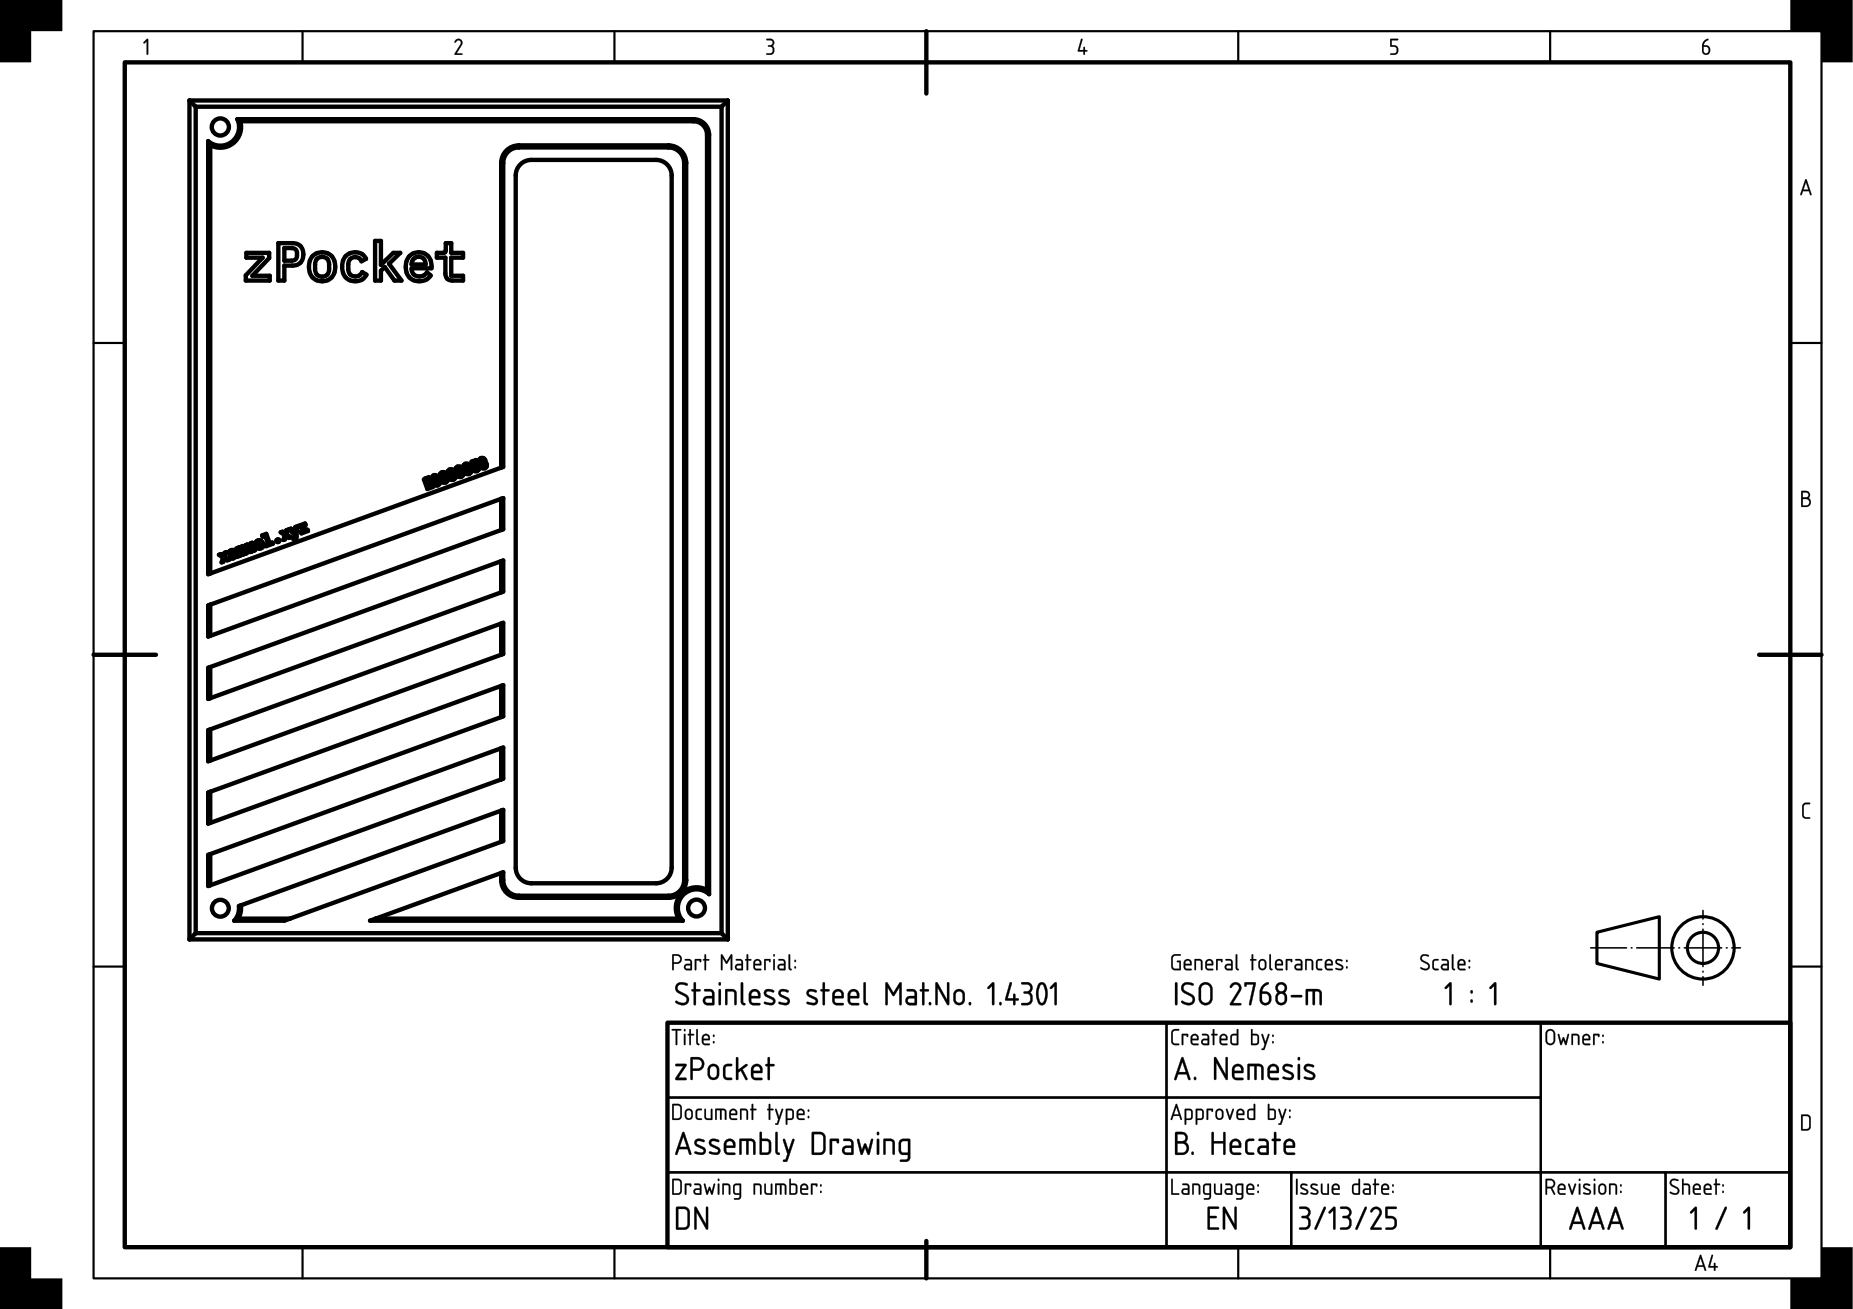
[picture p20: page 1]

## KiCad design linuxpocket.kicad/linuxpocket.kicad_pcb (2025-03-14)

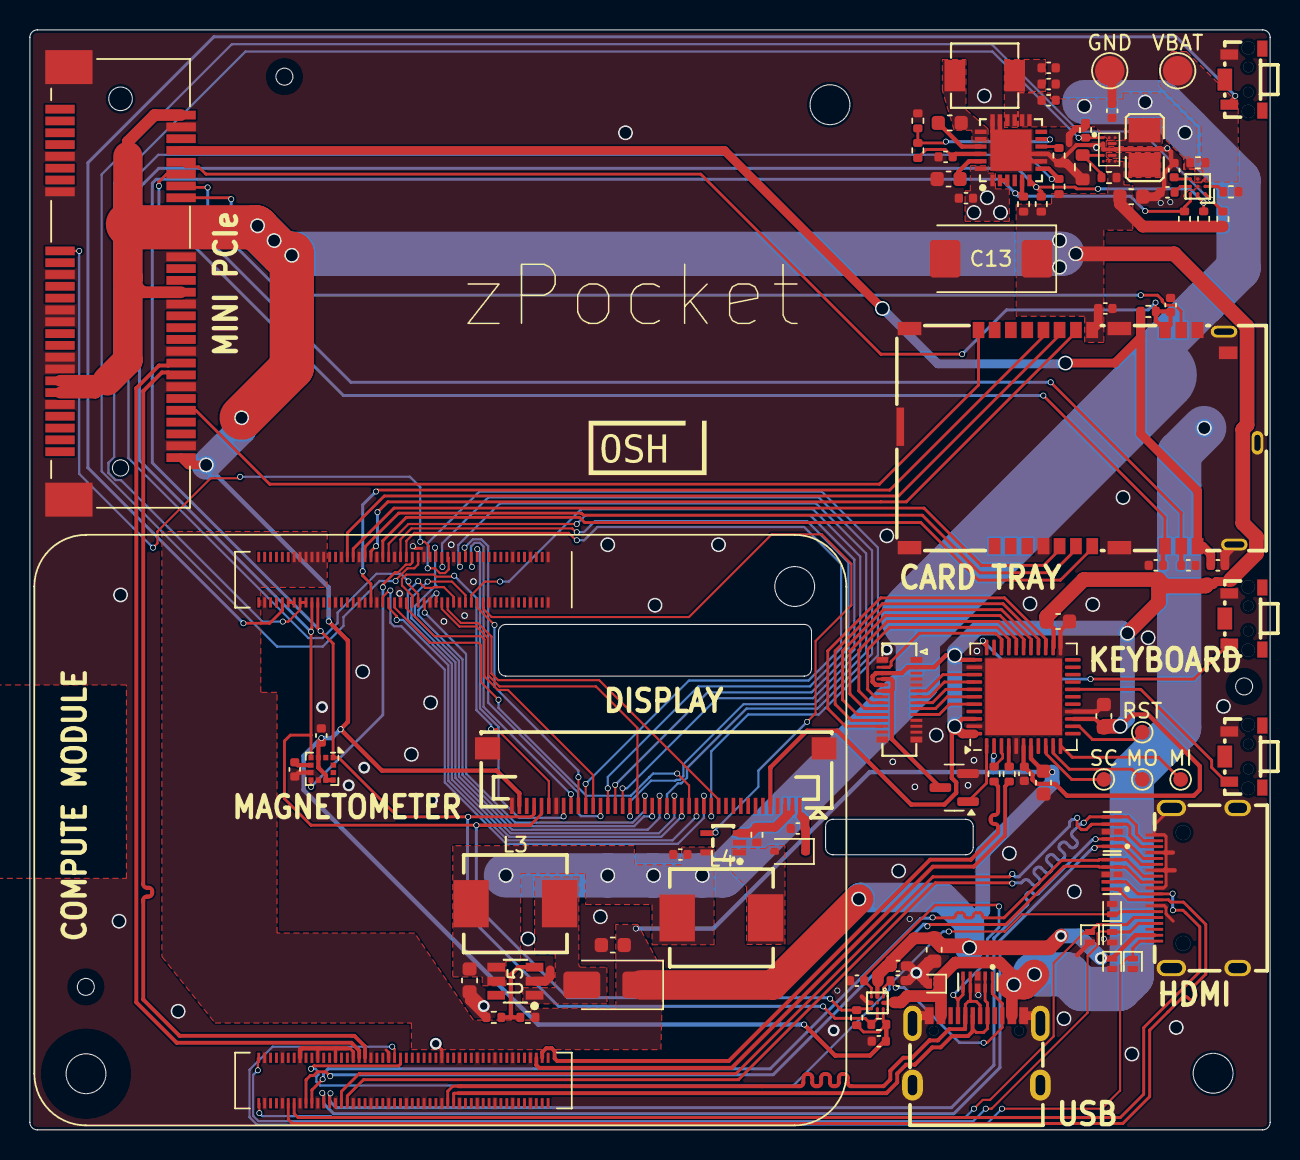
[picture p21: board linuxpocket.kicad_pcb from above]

Board: 4 copper layers, 84.0 x 74.5 mm, 94 parts (0 on the bottom side), 112 nets.

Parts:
C1, C4, C6, C7, C11, C32: 10uF; C_0402_1005Metric
C2, C10, C17, C18, C19, C22, C27, C28: 1uF; C_0402_1005Metric
C3, C23, C24, C25: 47nF; C_0603_1608Metric
C5, C9: 4.7uF; C_0402_1005Metric
C8, C12, C20, C21, C26: 22uF; C_0603_1608Metric
C13: 470uF; CP_EIA-7343-31_Kemet-D
C14, C15, C16: 33pF; C_0402_1005Metric
C29, C30: 220pF; C_0402_1005Metric
C31: 220nF; C_0402_1005Metric
D2: D_Schottky; D_SOD-323
D3: D_Schottky; D_SMA
D4, D5, D11: TPD4E02B04DQAR; USON-10_L2.5-W1.0-P0.50-BL
D6, D7, D8, D9, D10, D12: H5VL10B; D_SOD-882
FPC1: XF2M-4015-1A_C225713; FPC-SMD_40P-P0.50_L4.9-W23.5
GND: TestPoint_Pad_D2.0mm
J1: XDSM-1035-08-KT; SIM-SMD_XDSM-1035-08_1
J2: Bus_PCI_Express_Mini; BUS_PCI_Express_Mini_Full
J3: HDMI_C_1.4; HDMI-SMD_A71-05H4-111N1
J4: USB_C_Receptacle_USB2.0_14P; USB-SMD_TYPE-C16PIN-1
L1: 2.2uH; IND-SMD_L4.4-W4.2
L2: 0.47uH; L1008
L3, L4: 4.7uH; IND-SMD_L7.0-W6.6
MI: TestPoint; TestPoint_Pad_D1.0mm
MO: TestPoint; TestPoint_Pad_D1.0mm
Module1: ComputeModule4-CM4; Raspberry-Pi-4-Compute-Module
Q1: MMBT3904; SOT-23
R1, R2, R3, R8, R9, R10, R11, R15, R16, R21: 10k; R_0402_1005Metric
R4, R22: 22; R_0402_1005Metric
R6: 120; R_0402_1005Metric
R7, R20: 15k; R_0402_1005Metric
R12: 10mΩ; R_0402_1005Metric
R13: 510k; R_0402_1005Metric
R14: 91k; R_0603_1608Metric
R18: 4.7; R_0402_1005Metric
R19: 100k; R_0402_1005Metric
R26, R27: 4.7k; R_0402_1005Metric
RST: TestPoint; TestPoint_Pad_D1.0mm
SC: TestPoint; TestPoint_Pad_D1.0mm
SW1, SW2, SW3: PUSH; SW-SMD_GT-TC020B-H035-L05
U1: BQ24295RGER; VQFN-24_L4.0-W4.0-P0.50-TL-EP2.8
U2: BQ27426YZFR; DSBGA-9_L1.5-W1.5-R3-C3-P0.50-BL
U3: TPS63805YFFR; DSBGA-15_L2.3-W1.3-R5-C3-P0.40-TL
U4: TPS61169DCKR; SC-70-5_L2.1-W1.3-P0.65-LS2.1-BR
U5: MT3608L; SOT-23-6_L2.9-W1.6-P0.95-LS2.8-BL_3
U6: FUSB302BUCX; WLCSP-9_L1.3-W1.2-R3-C3-P0.40-TL
U7: BBQ10KBD; BM14B(0.8)-24DS-0.4V(53)
U8: ATmega32U4-M; QFN-44-1EP_7x7mm_P0.5mm_EP5.2x5.2mm
U9: LIS2MDL; LGA-12_2x2mm_P0.5mm
VBAT: TestPoint_Pad_D2.0mm

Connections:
+1V8: Module1.88 (+1.8v_(Output)), Module1.90 (+1.8v_(Output))
+3V3: C1.2, C12.1, C13.1, C22.1, C23.1, C24.1, C27.2, C32.2, FPC1.5, FPC1.39, J1.16 (VDD), J2.2 (+3V3AUX), J2.24 (+3V3AUX), J2.39 (+3V3AUX), J2.41 (+3V3AUX), J2.52 (+3V3AUX), R1.1, R2.1, R3.1, R9.1, R10.1, R11.1, R13.1, R26.1, R27.1, U3.E2 (VOUT), U3.E3 (VOUT), U6.A3 (VDD), U7.2 (MIC_VDD), U7.24 (LEDA_3_4), U7.26 (LEDA_1_2), U8.6 (UCAP), U8.14 (VCC), U8.24 (AVCC), U8.34 (VCC), U8.42 (AREF), U8.44 (AVCC), U9.3 (~CS), U9.9 (Vdd), U9.10 (Vdd_IO)
+5V: C21.1, C25.1, C26.1, C28.2, D3.1 (K), D10.1 (A1), J3.18 (+5V), Module1.77 (+5v_(Input)), Module1.79 (+5v_(Input)), Module1.81 (+5v_(Input)), Module1.83 (+5v_(Input)), Module1.85 (+5v_(Input)), Module1.87 (+5v_(Input)), R19.1, U6.B1 (VCONN), U8.2 (UVCC), U8.7 (VBUS)
/Battery and Power/3V3 EN: Module1.78 (GPIO_VREF(1.8v/3.3v_Input)), Module1.84 (+3.3v_(Output)), Module1.86 (+3.3v_(Output)), R21.1, U3.A1 (EN)
/Battery and Power/BACKLIGHT: Module1.24 (GPIO26), U4.4 (CTRL)
/Battery and Power/CHARGE_INT: Module1.46 (GPIO22), R3.2, U1.7 (INT)
/Battery and Power/CHARGE_NTC: R7.1, R8.2, U1.11 (TS)
/Battery and Power/GAUGE_GPOUT: Module1.45 (GPIO24), R9.2, U2.A1 (GPOUT)
/Battery and Power/LEDA: C19.2, D2.1 (K), FPC1.1
/Battery and Power/LEDK: FPC1.2, FPC1.3, R18.1, U4.3 (FB)
/Battery and Power/REGN: C5.1, R8.1, U1.22 (REGN)
/Battery and Power/SYS: C6.1, C7.1, L1.1, U1.15 (SYS), U1.16 (SYS)
/Battery and Power/VBATT: C10.2, R12.1, U2.C1 (SRP), U2.C3 (BAT), VBAT.1
/Battery and Power/VBUS: C2.1, D12.1 (A1), J4.A4 (VBUS), J4.B9 (VBUS), U1.1 (VBUS), U1.24 (VBUS), U6.A2 (VBUS)
/Battery and Power/VBload: C4.1, C11.1, C18.2, C20.1, L3.1, L4.1, R12.2, U1.13 (BAT), U1.14 (BAT), U2.C2 (SRN), U3.A2 (VIN), U3.A3 (VIN), U4.5 (VIN), U5.4 (EN), U5.5 (VIN)
/Battery and Power/VDD: C9.1, U2.B3 (VDD)
/GPIO/DE: FPC1.13, Module1.35 (ID_SC)
/GPIO/DPI_D0: FPC1.16, Module1.54 (GPIO4)
/GPIO/DPI_D1: FPC1.17, Module1.34 (GPIO5)
/GPIO/DPI_D2: FPC1.18, Module1.30 (GPIO6)
/GPIO/DPI_D3: FPC1.19, Module1.37 (GPIO7)
/GPIO/DPI_D4: FPC1.20, Module1.39 (GPIO8)
/GPIO/DPI_D5: FPC1.21, Module1.40 (GPIO9)
/GPIO/DPI_D6: FPC1.22, Module1.44 (GPIO10)
/GPIO/DPI_D7: FPC1.23, Module1.38 (GPIO11)
/GPIO/DPI_D8: FPC1.24, Module1.31 (GPIO12)
/GPIO/DPI_D9: FPC1.25, Module1.28 (GPIO13)
/GPIO/DPI_D10: FPC1.26, Module1.55 (GPIO14)
/GPIO/DPI_D11: FPC1.27, Module1.51 (GPIO15)
/GPIO/DPI_D12: FPC1.28, Module1.29 (GPIO16)
/GPIO/DPI_D13: FPC1.29, Module1.50 (GPIO17)
/GPIO/DPI_D14: FPC1.30, Module1.49 (GPIO18)
/GPIO/DPI_D15: FPC1.31, Module1.26 (GPIO19)
/GPIO/DPI_D16: FPC1.32, Module1.27 (GPIO20)
/GPIO/DPI_D17: FPC1.33, Module1.25 (GPIO21)
/GPIO/LCD_HSYNC: FPC1.15, Module1.56 (GPIO3)
/GPIO/LCD_VSYNC: FPC1.14, Module1.58 (GPIO2)
/GPIO/MAG_INT: Module1.47 (GPIO23), U9.7 (DRDY)
/GPIO/PCLK: FPC1.12, Module1.36 (ID_SD)
/GPIO/PWR_BUT: Module1.92 (RUN_PG), SW1.1
/GPIO/RI: J2.17 (UIM_C8), Module1.41 (GPIO25)
/GPIO/SD_CLK: J1.17 (CLK), Module1.57 (SD_CLK)
/GPIO/SD_CMD: J1.15 (CMD), Module1.62 (SD_CMD)
/GPIO/SD_DAT0: J1.19 (DAT0), Module1.63 (SD_DAT0)
/GPIO/SD_DAT1: J1.20 (DAT1), Module1.67 (SD_DAT1)
/GPIO/SD_DAT2: J1.13 (DAT2), Module1.69 (SD_DAT2)
/GPIO/SD_DAT3: J1.14 (CD/DAT3), Module1.61 (SD_DAT3)
/GPIO/SIM_CLK: C14.1, J1.3 (SIM1_CLK), J2.12 (UIM_CLK)
/GPIO/SIM_IO: C15.1, J1.6 (SIM1_I/O), J2.10 (UIM_DATA), R15.2
/GPIO/SIM_RST: C16.1, J1.2 (SIM1_RST), J2.14 (~UIM_RESET)
/GPIO/SIM_VCC: C17.1, J1.1 (SIM1_VCC), J2.8 (UIM_PWR), R15.1
/GPIO/SIM_VPP: J1.5 (SIM1_VPP), J2.16 (UIM_VPP)
/GPIO/TP_INT: FPC1.35, Module1.48 (GPIO27)
/GPIO/TRAY_SW: J1.21 (SW), J2.44 (~LED_WLAN)
/GPIO/VOL_DOWN: SW3.1, U8.18 (PD0)
/GPIO/VOL_UP: SW2.1, U8.33 (~HWB/PE2)
/High Speed/HDMI_CEC: D6.1 (A1), J3.14 (CEC), Module1.151 (HDMI0_CEC)
/High Speed/HDMI_CLK+: D5.2 (IO2), D5.9 (NC), J3.11 (CK+), Module1.188 (HDMI0_CLK_P)
/High Speed/HDMI_CLK-: D5.1 (IO1), D5.10 (NC), J3.12 (CK-), Module1.190 (HDMI0_CLK_N)
/High Speed/HDMI_HP: D9.1 (A1), J3.19 (HPD/HEAC-), Module1.153 (HDMI0_HOTPLUG)
/High Speed/HDMI_SCL: D7.1 (A1), J3.15 (SCL), Module1.200 (HDMI0_SCL)
/High Speed/HDMI_SDA: D8.1 (A1), J3.16 (SDA), Module1.199 (HDMI0_SDA)
/High Speed/HDMI_TX0+: D5.5 (IO4), D5.6 (NC), J3.8 (D0+), Module1.182 (HDMI0_TX0_P)
/High Speed/HDMI_TX0-: D5.4 (IO3), D5.7 (NC), J3.9 (D0-), Module1.184 (HDMI0_TX0_N)
/High Speed/HDMI_TX1+: D4.2 (IO2), D4.9 (NC), J3.5 (D1+), Module1.176 (HDMI0_TX1_P)
/High Speed/HDMI_TX1-: D4.1 (IO1), D4.10 (NC), J3.6 (D1-), Module1.178 (HDMI0_TX1_N)
/High Speed/HDMI_TX2+: D4.5 (IO4), D4.6 (NC), J3.2 (D2+), Module1.170 (HDMI0_TX2_P)
/High Speed/HDMI_TX2-: D4.4 (IO3), D4.7 (NC), J3.3 (D2-), Module1.172 (HDMI0_TX2_N)
/High Speed/USB2-D_N: Module1.103 (USB2_N), R4.2
/High Speed/USB2-D_P: Module1.105 (USB2_P), R22.1
/High Speed/USB3-0-D_N: D11.4 (IO3), D11.7 (NC), J4.A7 (D-), J4.B7 (D-), Module1.136 (CAM0_D1_P)
/High Speed/USB3-0-D_P: D11.2 (IO2), D11.9 (NC), J4.A6 (D+), J4.B6 (D+), Module1.134 (CAM0_D1_N)
/High Speed/USB3-1-D_N: J2.36 (USB_D-), Module1.165 (DSI0_D1_P)
/High Speed/USB3-1-D_P: J2.38 (USB_D+), Module1.163 (DSI0_D1_N)
/Keyboard/MISO: MI.1, U8.11 (PB3)
/Keyboard/MOSI: MO.1, U8.10 (PB2)
/Keyboard/RESET: RST.1, U8.13 (~RESET)
/Keyboard/SCK: SC.1, U8.9 (PB1)
/SCL: FPC1.37, Module1.80 (SCL0), R1.2, R11.2, R27.2, U1.5 (SCL), U2.A3 (SCL), U6.B3 (SCL), U9.1 (SCL/SPC)
/SDA: FPC1.36, Module1.82 (SDA0), R2.2, R10.2, R26.2, U1.6 (SDA), U2.A2 (SDA), U6.C3 (SDA), U9.4 (SDA/SDI/SDO)
/hs_io/CC1: C29.1, D11.5 (IO4), D11.6 (NC), J4.A5 (CC1), U6.C1 (CC1)
/hs_io/CC2: C30.1, D11.1 (IO1), D11.10 (NC), J4.B5 (CC2), U6.A1 (CC2)
GND: C1.1, C2.2, C4.2, C5.2, C6.2, C7.2, C8.1, C9.2, C10.1, C11.2, C12.2, C13.2, C14.2, C15.2, C16.2, C17.2, C18.1, C19.1, C20.2, C21.2, C22.2, C23.2, C24.2, C25.2, C26.2, C27.1, C28.1, C29.2, C30.2, C31.2, C32.1, D4.3 (GND), D4.8 (GND), D5.3 (GND), D5.8 (GND), D6.2 (A2), D7.2 (A2), D8.2 (A2), D9.2 (A2), D10.2 (A2), D11.3 (GND), D11.8 (GND), D12.2 (A2), FPC1.0, FPC1.4, FPC1.34, FPC1.40, GND.1, J1.4 (SIM1_GND), J1.18 (VSS), J1.22 (GND), J1.23 (GND), J1.24 (GND), J1.25 (GND), J1.26 (GND), J1.27 (GND), J1.28 (GND), J1.29 (GND), J1.30 (GND), J2.4 (GND), J2.9 (GND), J2.15 (GND), J2.18 (GND), J2.21 (GND), J2.26 (GND), J2.27 (GND), J2.29 (GND), J2.34 (GND), J2.35 (GND), J2.37 (GND), J2.40 (GND), J2.43 (GND), J2.50 (GND), J2.MP, J3.1 (D2S), J3.4 (D1S), J3.7 (D0S), J3.10 (CKS), J3.13 (GND), J3.20, J3.21, J3.22, J3.23, J4.A1 (GND), J4.B1 (GND), J4.S1 (SHIELD), Module1.1 (GND), Module1.2 (GND), Module1.7 (GND), Module1.8 (GND), Module1.13 (GND), Module1.14 (GND), Module1.22 (GND), Module1.23 (GND), Module1.32 (GND), Module1.33 (GND), Module1.42 (GND), Module1.43 (GND), Module1.52 (GND), Module1.53 (GND), Module1.59 (GND), Module1.60 (GND), Module1.65 (GND), Module1.66 (GND), Module1.71 (GND), Module1.74 (GND), Module1.98 (GND), Module1.107 (GND), Module1.108 (GND), Module1.113 (GND), Module1.114 (GND), Module1.119 (GND), Module1.120 (GND), Module1.125 (GND), Module1.126 (GND), Module1.131 (GND), Module1.132 (GND), Module1.137 (GND), Module1.138 (GND), Module1.144 (GND), Module1.150 (GND), Module1.155 (GND), Module1.156 (GND), Module1.161 (GND), Module1.162 (GND), Module1.167 (GND), Module1.168 (GND), Module1.173 (GND), Module1.174 (GND), Module1.179 (GND), Module1.180 (GND), Module1.185 (GND), Module1.186 (GND), Module1.191 (GND), Module1.192 (GND), Module1.197 (GND), Module1.198 (GND), Q1.2 (E), R6.2, R7.2, R14.2, R16.2, R18.2, R20.2, R21.2, SW1.2, SW2.2, SW3.2, U1.8 (OTG), U1.9 (CE), U1.17 (PGND), U1.18 (PGND), U1.25 (EP), U2.B2 (VSS), U3.B1 (MODE), U3.C1 (AGND), U3.C2 (GND), U3.C3 (GND), U4.2 (GND), U5.2 (GND), U6.C2 (GND), U7.1 (GND), U7.4 (AGND), U7.5 (GND), U7.11 (GND), U7.12 (GND), U7.13 (GND), U7.14 (GND), U7.15 (GND), U7.16 (GND), U7.28 (GND), U8.5 (UGND), U8.15 (GND), U8.23 (GND), U8.35 (GND), U8.43 (GND), U8.45 (GND), U9.6 (GND), U9.8 (GND)
unnamed: C3.1, L1.2, U1.19 (SW), U1.20 (SW)
unnamed: D2.2 (A), L4.2, U4.1 (SW)
unnamed: D3.2 (A), L3.2, U5.1 (SW)
unnamed: L2.1, U3.B2 (L1), U3.B3 (L1)
unnamed: L2.2, U3.D2 (L2), U3.D3 (L2)
unnamed: Q1.1 (B), U8.1 (PE6)
unnamed: Q1.3 (C), U7.23 (LEDK_2_3), U7.25 (LEDK_1_4)
unnamed: C3.2, U1.21 (BTST)
unnamed: U1.2 (D+), U1.3 (D-)
unnamed: R6.1, U1.10 (ILIM)
unnamed: C8.2, U1.23 (PMID)
unnamed: R16.1, U2.B1 (BIN)
unnamed: R13.2, R14.1, U3.D1 (FB)
unnamed: R19.2, R20.1, U5.3 (FB)
unnamed: U7.7 (COL1), U8.37 (PF6)
unnamed: U7.9 (COL2), U8.39 (PF4)
unnamed: U7.10 (COL3), U8.40 (PF1)
unnamed: U7.17 (COL4), U8.25 (PD4)
unnamed: U7.19 (COL5), U8.27 (PD7)
unnamed: U7.6 (ROW1), U8.36 (PF7)
unnamed: U7.8 (ROW2), U8.38 (PF5)
unnamed: U7.18 (ROW3), U8.26 (PD6)
unnamed: U7.20 (ROW4), U8.28 (PB4)
unnamed: U7.21 (ROW5), U8.29 (PB5)
unnamed: U7.22 (ROW6), U8.30 (PB6)
unnamed: U7.27 (ROW7), U8.31 (PC6)
unnamed: R22.2, U8.4 (D+)
unnamed: R4.1, U8.3 (D-)
unnamed: C31.1, U9.5 (C1)

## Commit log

2025-01-26 Add keyboard, improve many things etc.
    [CM4IOv5-B_Cu.gbr, CM4IOv5-B_Mask.gbr, CM4IOv5-Edge_Cuts.gbr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]
2025-01-26 Keyboard done. (Except mic) #2
    [keyboard.kicad_sch]
2025-01-28 Start with HDMI connector.
    [Power.kicad_sch, gpio.kicad_sch, highspeed.kicad_sch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]
2025-01-29 Finish HDMI
    [hs_io.kicad_sch, linuxpocket.kicad_sch]
2025-02-01 Finish USB-C. #1
    [hs_io.kicad_sch, linuxpocket.kicad_sch]
2025-02-02 Add magnetometer #5. Add footprints to some symbols.
    [Power.kicad_sch, gpio.kicad_sch, highspeed.kicad_sch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]
2025-02-02 Start placing components in PCB.
    [gpio.kicad_sch, highspeed.kicad_sch, hs_io.kicad_sch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]
2025-02-25 PCB almost done and schematic finished.
    [Power.kicad_sch, gpio.kicad_sch, highspeed.kicad_sch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]
2025-03-04 PCB basically finished.
    [gpio.kicad_sch, highspeed.kicad_sch, linuxpocket.kicad_pcb]
2025-03-05 Start case design.
    [linuxpocket.kicad_pcb, pcb.step]
2025-03-07 Progressing with case design.
    [linuxpocket.kicad_pcb, pcb.step]
2025-03-08 Improving Case design
2025-03-09 PCB fabrication info.
    [linuxpocket.kicad_pcb]
2025-03-14 PCB ordered, updated images
    [drawing.dxf, linuxpocket.kicad_pcb, zPocket-Back.dfx.step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]

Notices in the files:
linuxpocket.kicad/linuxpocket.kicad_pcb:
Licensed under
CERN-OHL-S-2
